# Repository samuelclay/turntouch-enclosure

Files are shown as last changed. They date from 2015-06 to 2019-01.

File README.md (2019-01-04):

# Turn Touch Enclosure - CAD & CAM design files
> All the design files used to make the plastic and wood enclosure in both CAD and CAM

<a href="https://turntouch.com"><br />Available at turntouch.com</a>

[][license-url]



## Screenshots of the Turn Touch enclosure

### Remote stack up


### Wooden case machine fixture


Machining remotes | Machining buttons
:---:|:---:
|  |  | 

## Background

You can read the complete documentation and background on the [Turn Touch blog series](http://ofbrooklyn.com/2019/01/3/building-turntouch/#cad).

## Features

[Turn Touch](https://turntouch.com) is a smart home remote control carved out of beautiful mahogany wood. This is a remote control for Hue lights, Sonos speakers, and all the other connected devices in your home. Turn Touch works on iOS and macOS, giving you control of your music, videos, presentations, and more. 

- [x] **Extraordinary design**: This isn't yet another plastic remote. Turn Touch is carved from solid wood and worked to a show-stopping, textured finish. 
- [x] **Well connected**: Turn Touch connects to most smart devices in your home that speak WiFi. And this is just the first version. Over time, there's no telling what you'll be able to control.
- [x] **Always ready**: Turn Touch is always on, always connected, and always ready to take your breath away. Once you connect your Turn Touch via Bluetooth it stays connected and always available, even without the Turn Touch app actively running. And there's no delay, when you press a button the result is instant.
- [x] **Built to last**: Not only will your Turn Touch stand up to drops and shock — its entire circuit board can be inexpensively replaced with newer, future wireless tech. You won't have to buy a new remote every time Apple comes out with a new phone. And instead of flimsy plastic clasps, a set of 8 strong magnets invisibly hold the remote together. 

## Requirements

- Windows 10
- Autodesk Inventor 2018

## Contribute

We would love you for the contribution to the **Turn Touch enclosure**. Submit a Pull Request with your changes or additions and I'd love to talk about merging it. 

## Turn Touch open source repositories and documentation

Everything about Turn Touch is open source and well documented. Here are all of Turn Touch's repos:

* [Turn Touch Mac OS app](https://github.com/samuelclay/turntouch-mac/)
* [Turn Touch iOS app](https://github.com/samuelclay/turntouch-ios/)
* [Turn Touch remote firmware and board layout](https://github.com/samuelclay/turntouch-remote/)
* [Turn Touch enclosure, CAD, and CAM](https://github.com/samuelclay/turntouch-enclosure/)

The entire Turn Touch build process is also documented:
* <a href="http://ofbrooklyn.com/2019/01/3/building-turntouch/">Everything you need to build your own Turn Touch smart remote<br /></a>
* <a href="http://ofbrooklyn.com/2019/01/3/building-turntouch/#firmware">Step one: Laying out the buttons and writing the firmware <br /></a>
* <a href="http://ofbrooklyn.com/2019/01/3/building-turntouch/#cad">Step two: Designing the remote to have perfect button clicks <br /></a>
* <a href="http://ofbrooklyn.com/2019/01/3/building-turntouch/#cnc">Step three: CNC machining and fixturing to accurately cut wood <br /></a>
* <a href="http://ofbrooklyn.com/2019/01/3/building-turntouch/#laser">Step four: Inlaying the mother of pearl <br /></a>

## Author

Samuel Clay – [@samuelclay](https://twitter.com/samuelclay) – [samuelclay.com](http://samuelclay.com)

Distributed under the MIT license. See ``LICENSE`` for more information.

[https://github.com/samuelclay/turntouch-mac](https://github.com/samuelclay)

[swift-image]:https://img.shields.io/badge/swift-3.0-orange.svg
[swift-url]: https://swift.org/
[license-image]: https://img.shields.io/badge/License-MIT-blue.svg
[license-url]: LICENSE
[travis-image]: https://img.shields.io/travis/dbader/node-datadog-metrics/master.svg?style=flat-square
[travis-url]: https://travis-ci.org/dbader/node-datadog-metrics
[codebeat-image]: https://codebeat.co/badges/c19b47ea-2f9d-45df-8458-b2d952fe9dad
[codebeat-url]: https://codebeat.co/projects/github-com-vsouza-awesomeios-com

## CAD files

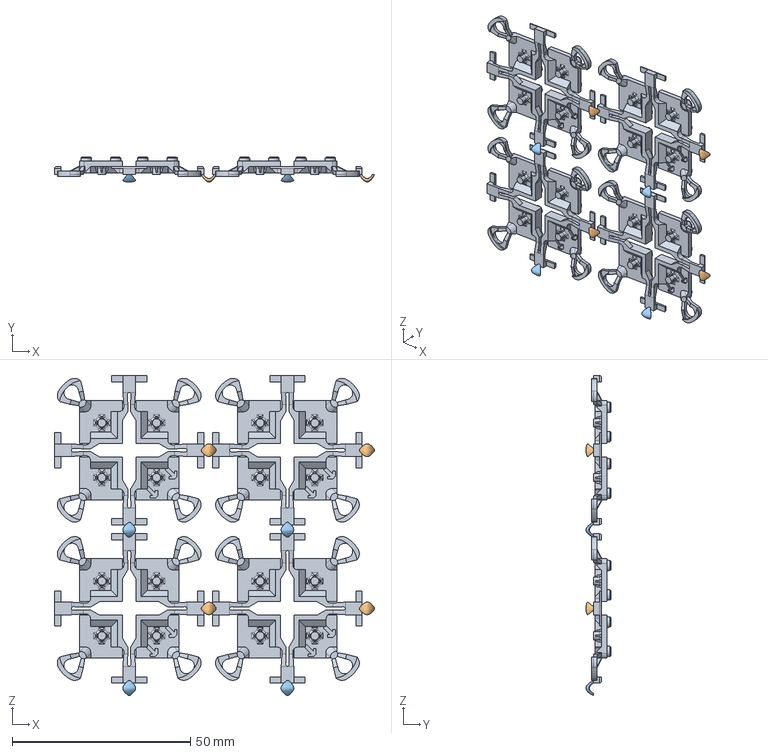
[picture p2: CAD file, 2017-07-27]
inventor/STEPs/Remote Buttons Print Assembly.stp
89.9 x 7.06 x 89.9 mm
Remote Buttons x 4

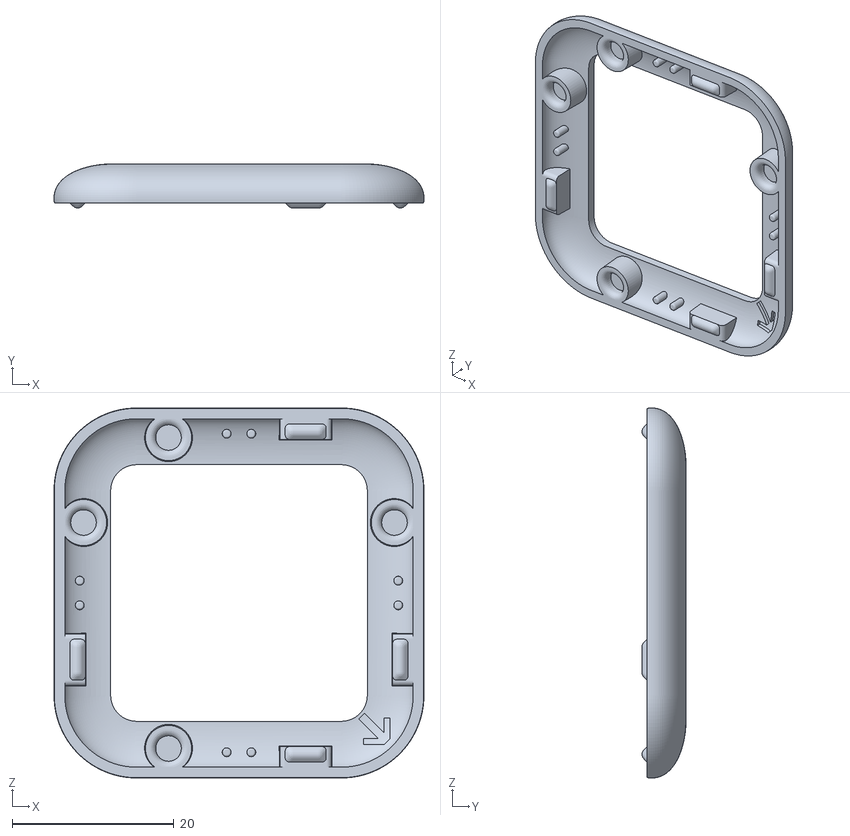
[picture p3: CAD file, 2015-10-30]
revisions/Turn Touch Remote Rev. 29/Remote Assembly_Remote Top_1.stl
45.8 x 5.45 x 45.8

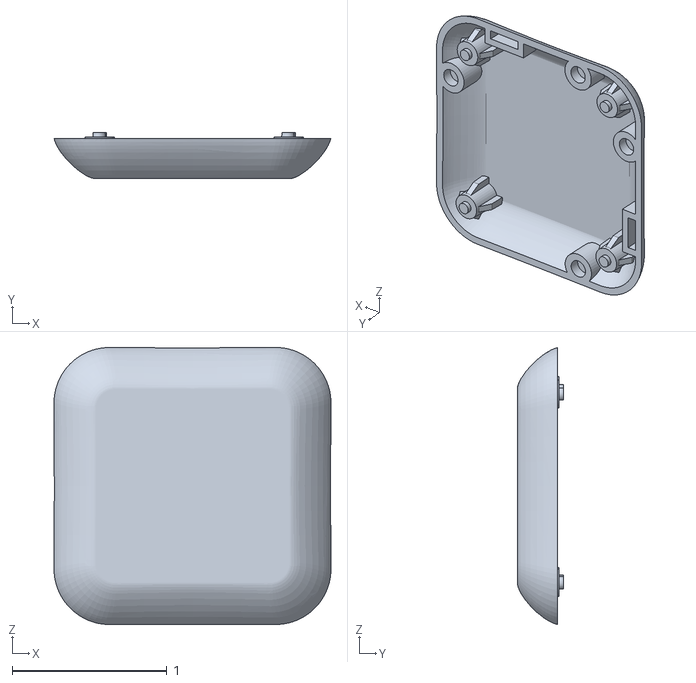
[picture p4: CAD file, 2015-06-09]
solidworks/STLs/Remote Assembly - Remote Bottom-1.STL
1.79 x 0.3 x 1.79

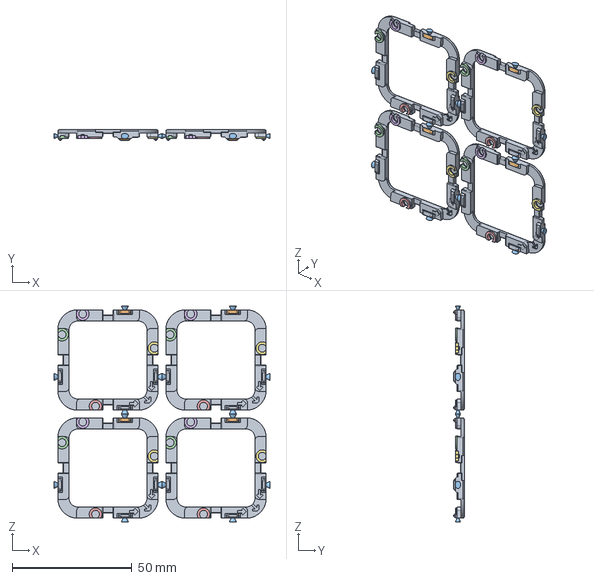
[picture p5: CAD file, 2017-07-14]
inventor/STEPs/Remote Top Print Assembly.stp
90.3 x 4.48 x 90.3 mm
Remote Top x 4

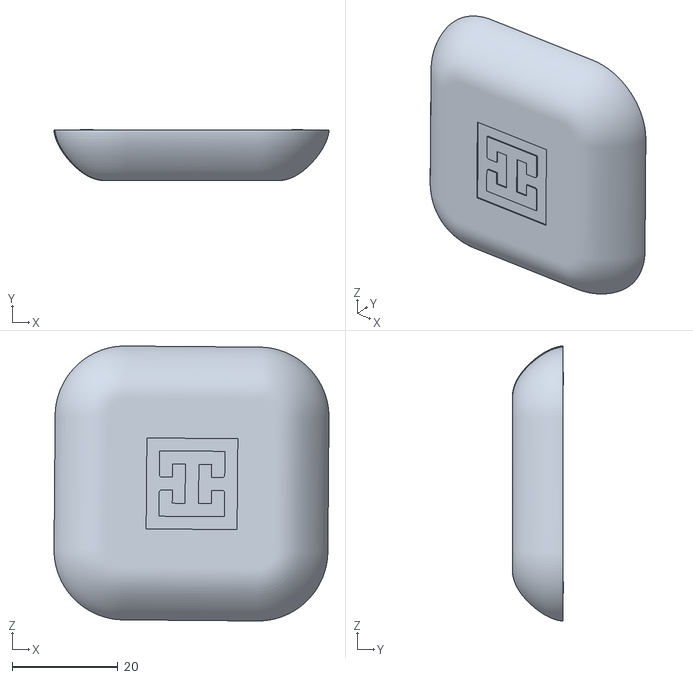
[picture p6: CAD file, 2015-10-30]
revisions/Turn Touch Remote Rev. 29/Remote Assembly_Case Bottom_5.stl
52.1 x 9.75 x 52.1

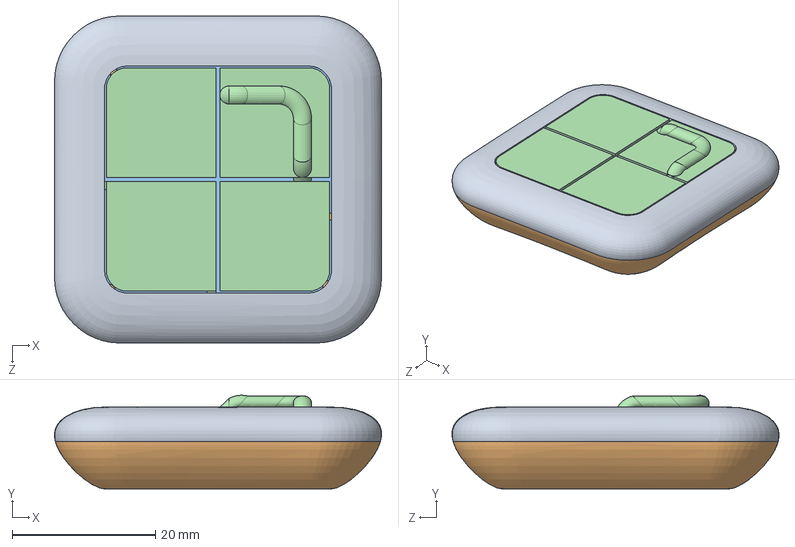
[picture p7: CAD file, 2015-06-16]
solidworks/Remote Assembly.SLDASM
45.7 x 13.1 x 45.7 mm
Remote Top
Remote Buttons

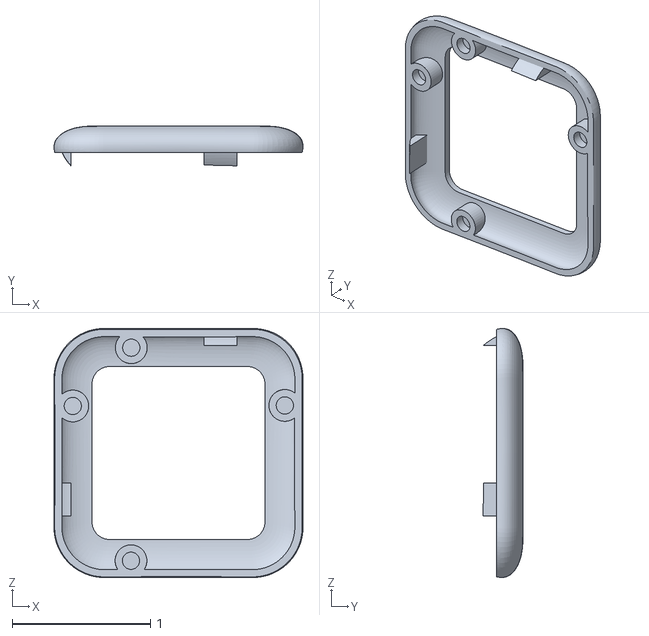
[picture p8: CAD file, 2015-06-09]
solidworks/STLs/Remote Assembly - Remote Top-1.STL
1.80 x 0.29 x 1.80

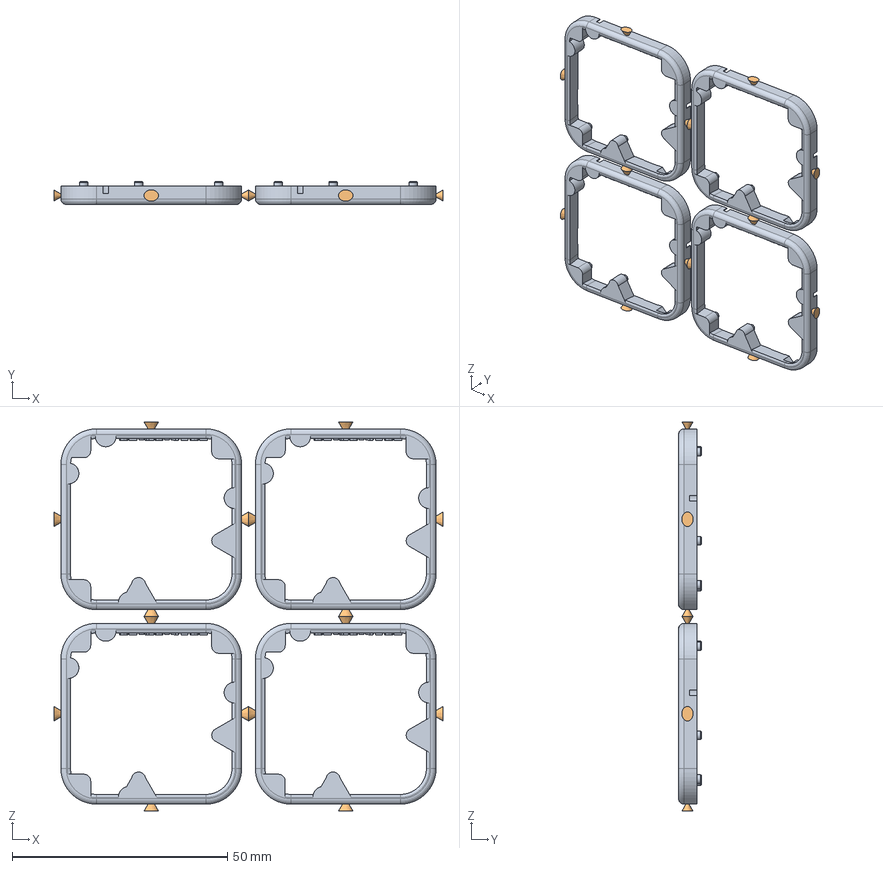
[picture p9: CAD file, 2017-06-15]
inventor/STEPs/Remote Bottom Print Assembly.stp
90.3 x 5.33 x 90.3 mm
Remote Bottom x 4

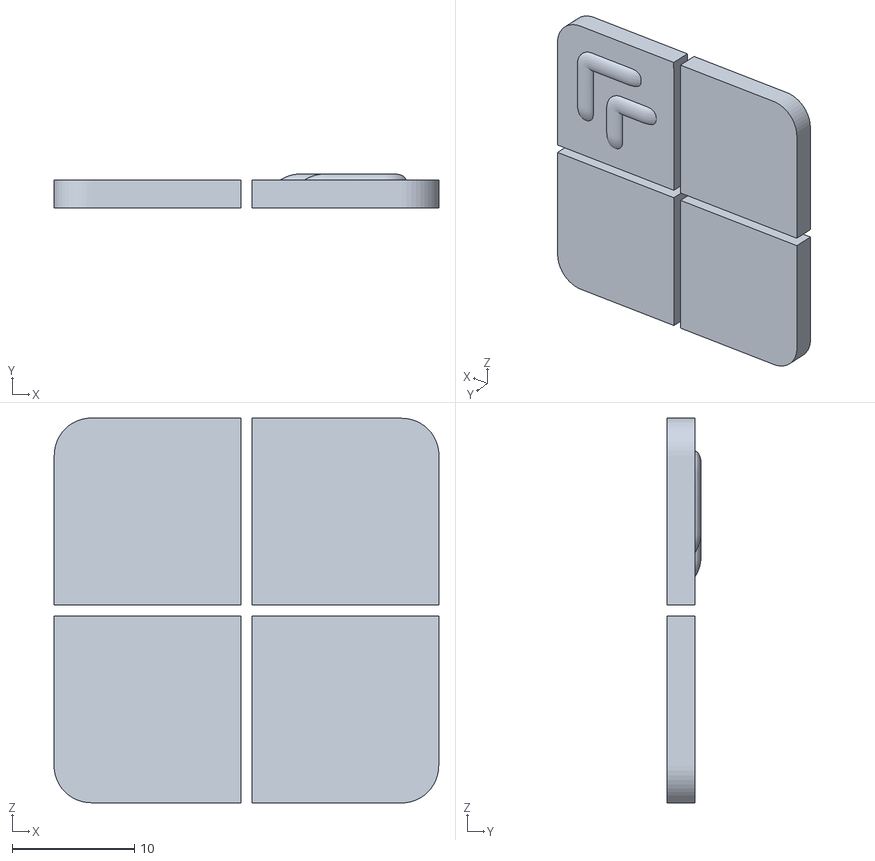
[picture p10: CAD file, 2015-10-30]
revisions/Turn Touch Remote Rev. 29/Remote Assembly_Case Buttons_6.stl
31.5 x 2.79 x 31.5

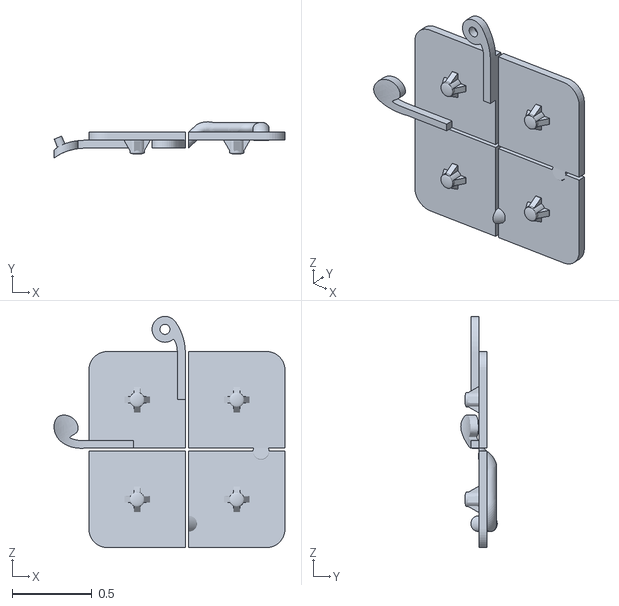
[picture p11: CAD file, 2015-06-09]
solidworks/STLs/Remote Assembly - Remote Buttons-1.STL
1.45 x 0.229 x 1.45

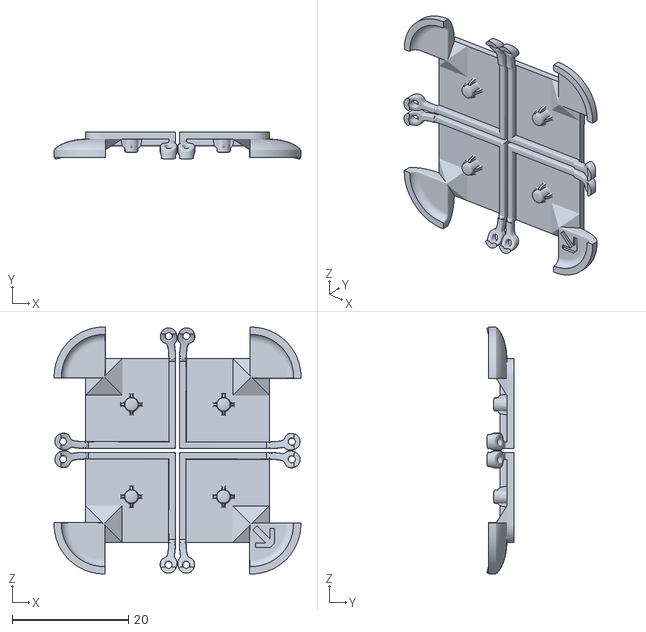
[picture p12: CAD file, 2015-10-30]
revisions/Turn Touch Remote Rev. 29/Remote Assembly_Remote Buttons_2.stl
42.6 x 4.73 x 42.6

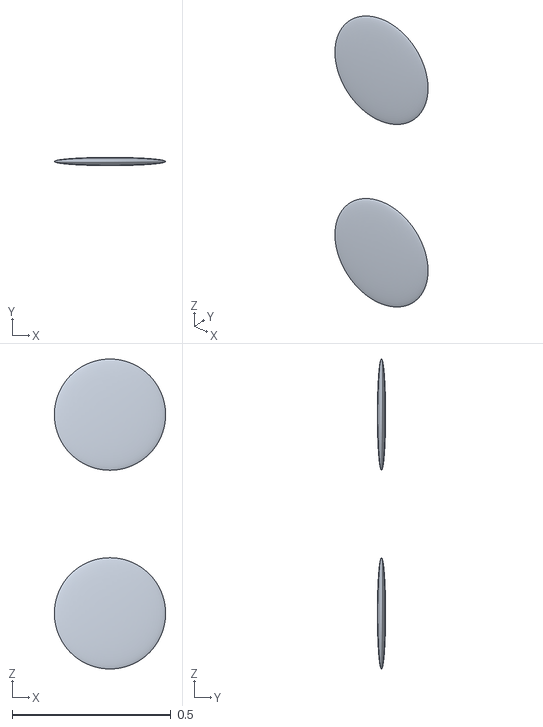
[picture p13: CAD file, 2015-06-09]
solidworks/STLs/Remote Assembly - PCB-3.STL
0.35 x 0.026 x 0.975

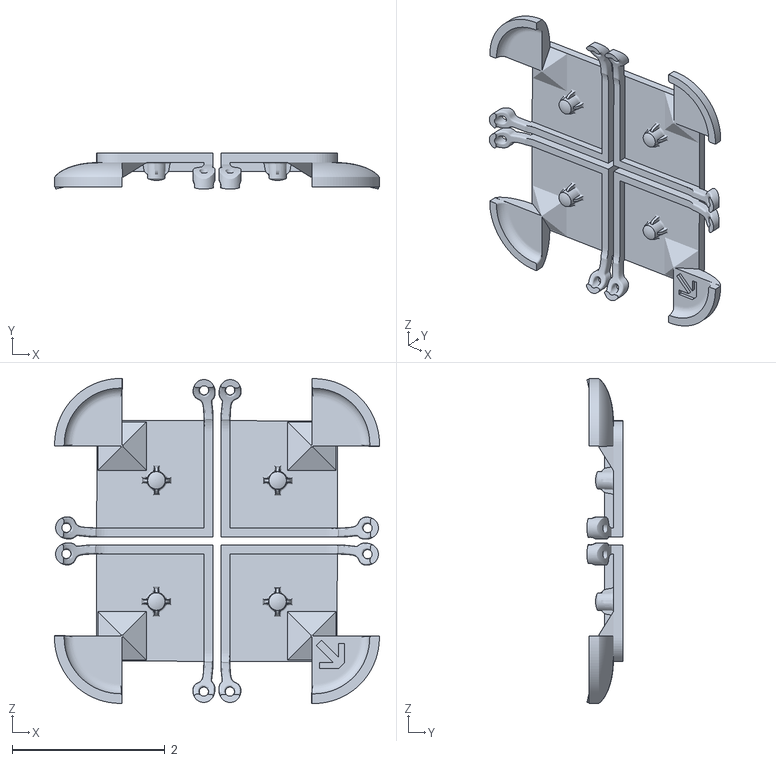
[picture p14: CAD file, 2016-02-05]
inventor/STLs/Remote Assembly_Remote Buttons_2.stl
4.26 x 0.473 x 4.26

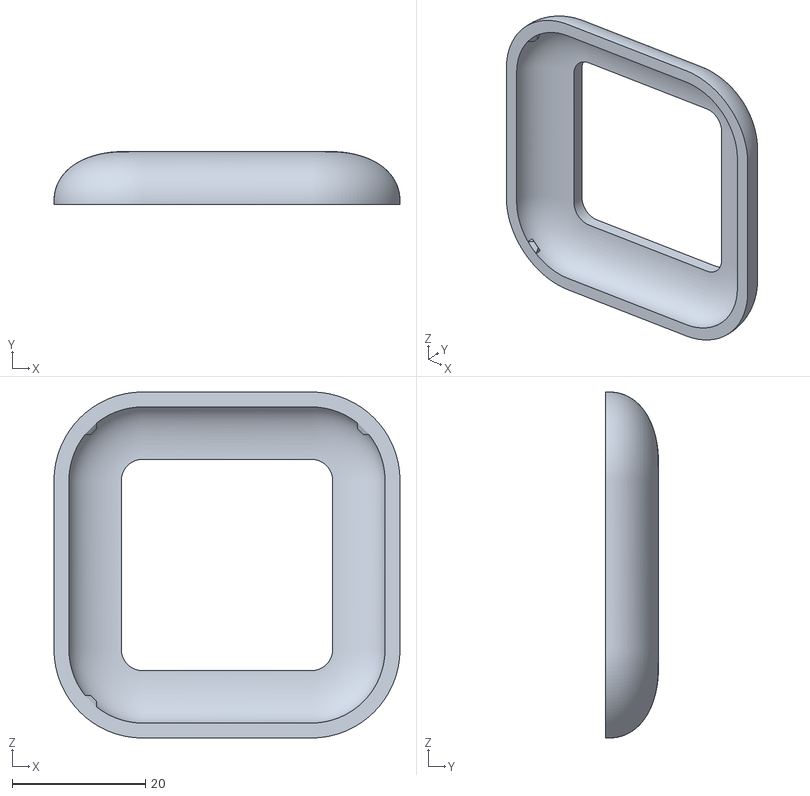
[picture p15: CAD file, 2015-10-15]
revisions/Turn Touch Remote Rev. 29/Remote Assembly_Case Top_4.stl
52.0 x 7.92 x 52.0

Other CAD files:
inventor/STLs/Remote Assembly_Remote Top_1.stl
revisions/Turn Touch Remote Rev. 29/Remote Assembly_Eagle PCB rev 21_7.stl
inventor/STLs/Remote Assembly_Remote Bottom_3.stl
revisions/Turn Touch Remote Rev. 29/Remote Assembly_Remote Bottom_3.stl
Remote Enclosure v2.3dm
Remote Enclosure.skp
Remote enclosure.obj
Remote r14.3dm
archive/rhino/archive/Remote Enclosure v2.3dm
archive/rhino/archive/Remote enclosure.obj
archive/rhino/bottom.stl
archive/rhino/bottom.stp
archive/rhino/bottoms.stp
archive/rhino/button.stl
archive/rhino/button.stp
archive/rhino/buttons.stp
archive/rhino/remote.stp
archive/rhino/top.stl
archive/rhino/top.stp
archive/rhino/tops.stp
archive/sketchup/Remote Enclosure.skp
archive/solidworks/PCB.SLDPRT
archive/solidworks/Remote Assembly.SLDASM
archive/solidworks/Remote Bottom.sldprt
archive/solidworks/Remote Buttons.SLDPRT
archive/solidworks/Remote Shell.SLDPRT
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

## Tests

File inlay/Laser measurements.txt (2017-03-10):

0) Split the case into the top and bottom

   Case width: 2.04"
   Case height: 0.35"

1) Run 'Case Outline' on spoil board

   Select: Center
   Z: 0.75"
   X: (23.5-2.04/2) = 22.48"
   Y: (0.5+2.04/2) = 1.52"

2) Run 'Engraver' on remote case with north ridge, facing down, pointing top left (horizontal mirror)

   Select: Center
   Z: (0.75+0.35) = 1.1"
   X: (23.5-2.04/2) = 22.48"
   Y: (0.5+2.04/2) = 1.52"

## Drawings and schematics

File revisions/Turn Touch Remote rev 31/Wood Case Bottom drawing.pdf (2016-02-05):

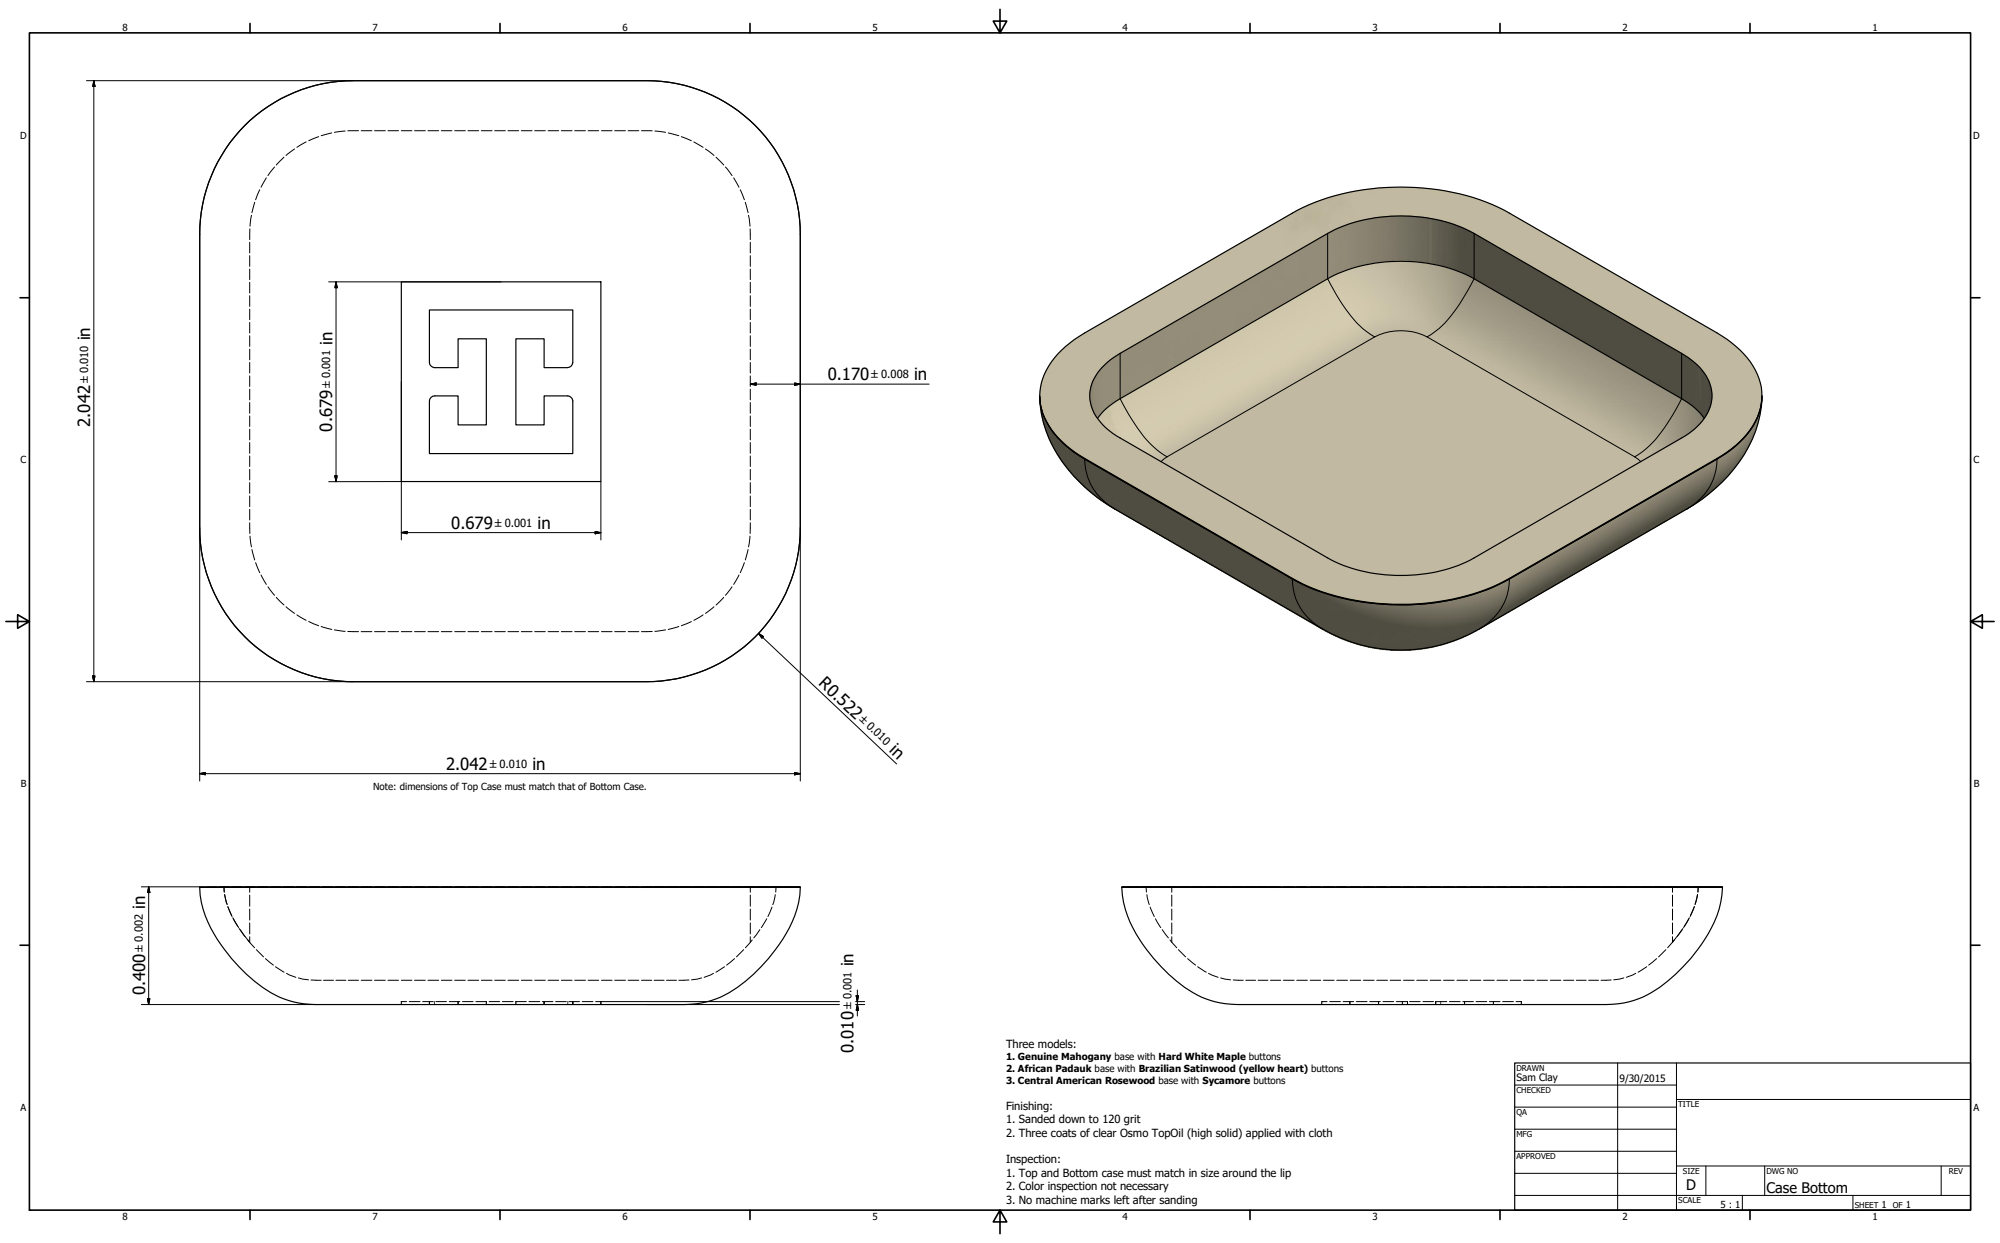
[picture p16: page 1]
SHEET 1 OF 1; DRAWN; CHECKED; MFG; APPROVED; Sam Clay; DWG NO Case Bottom; TITLE; SIZE D; SCALE; REV

Note: dimensions of Top Case must match that of Bottom Case.

Three models:
1. Genuine Mahogany base with Hard White Maple buttons
2. African Padauk base with Brazilian Satinwood (yellow heart) buttons
3. Central American Rosewood base with Sycamore buttons

Finishing:
1. Sanded down to 120 grit
2. Three coats of clear Osmo TopOil (high solid) applied with cloth

Inspection:
1. Top and Bottom case must match in size around the lip
2. Color inspection not necessary
3. No machine marks left after sanding

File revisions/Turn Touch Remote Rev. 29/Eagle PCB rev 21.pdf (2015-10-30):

1.450 in

0.080 in

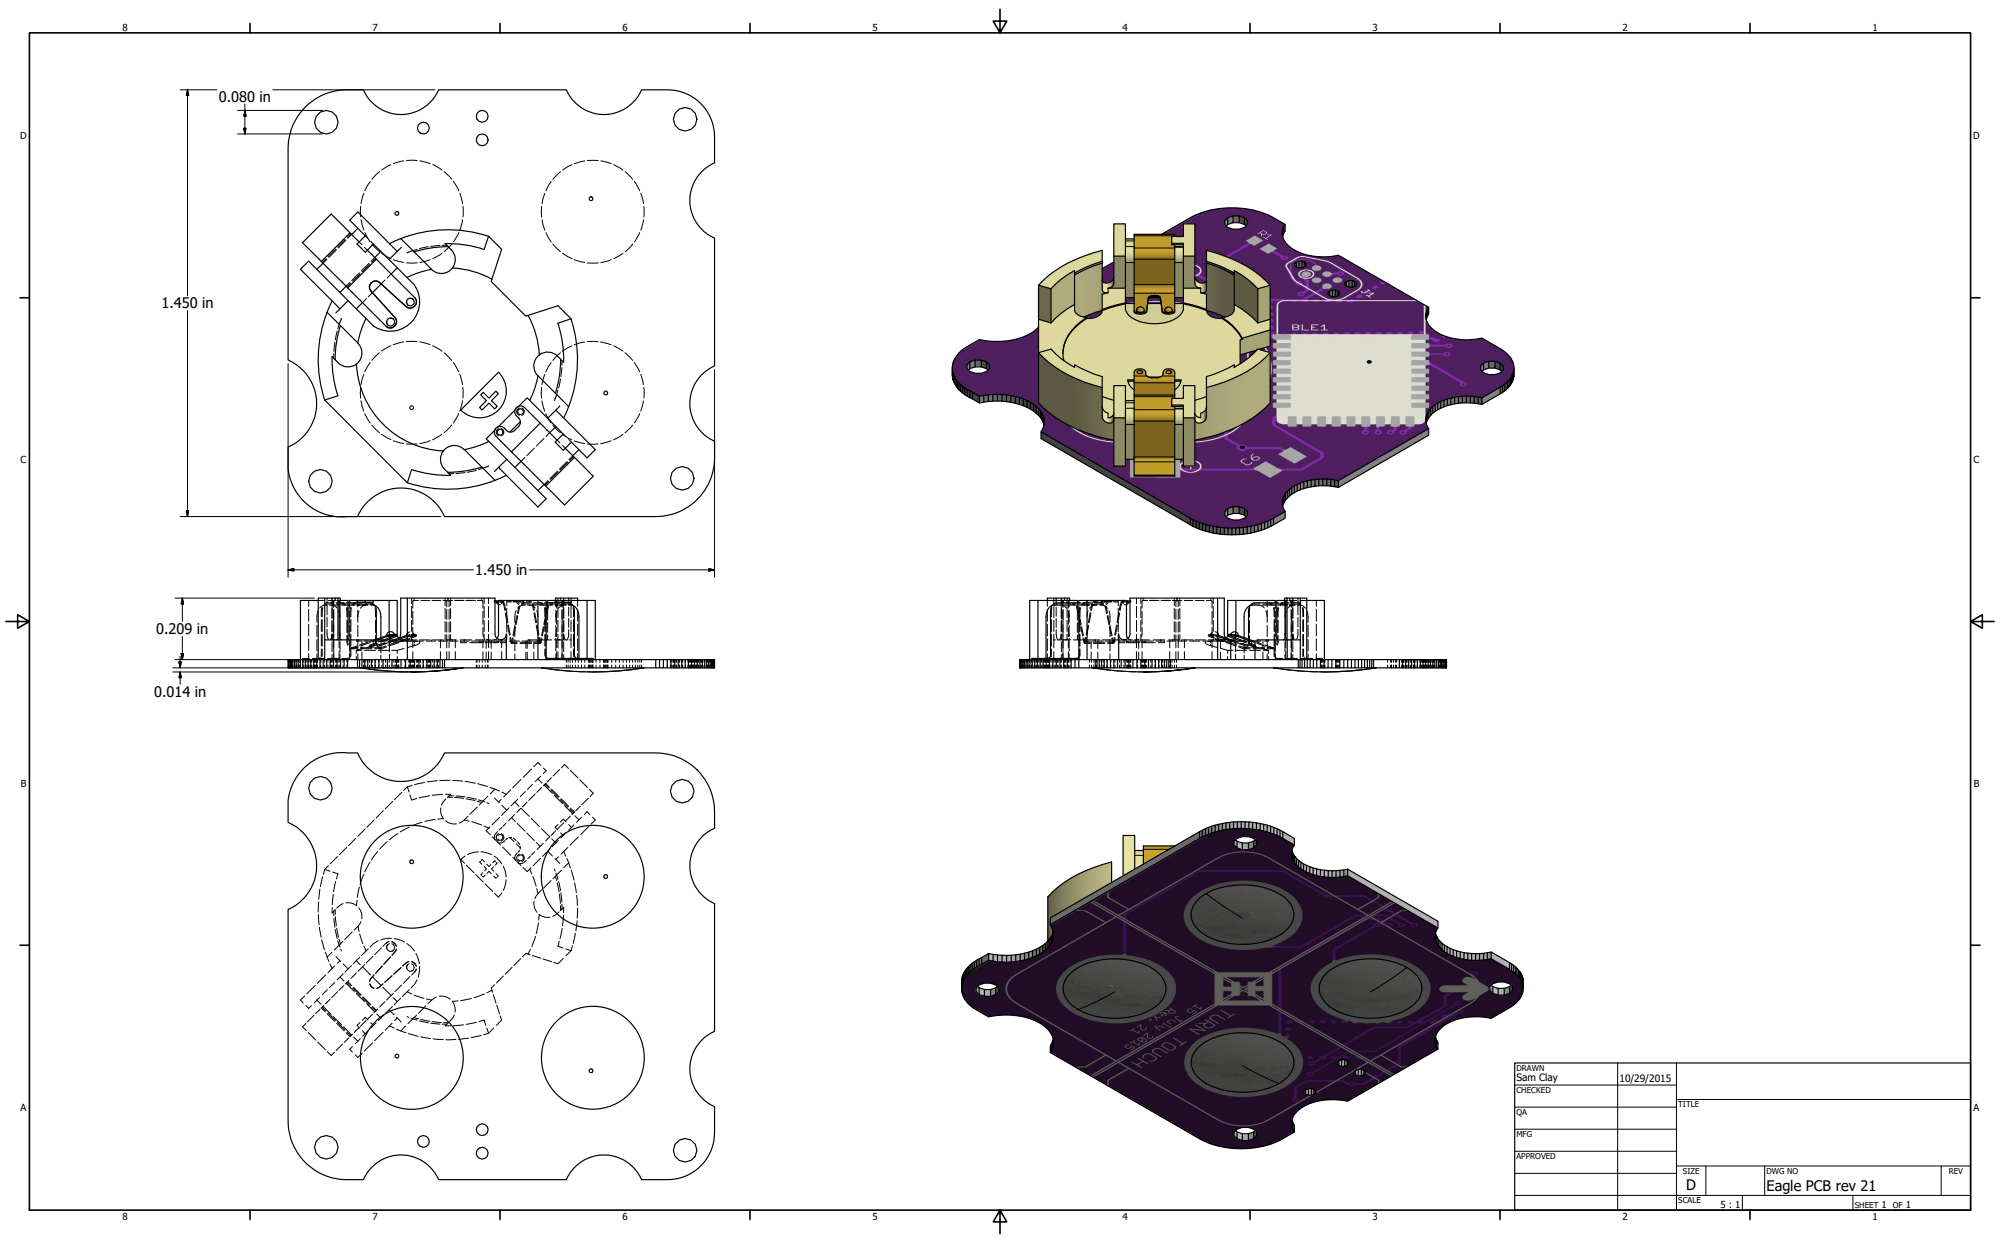
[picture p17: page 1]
SHEET 1 OF 1; DRAWN; CHECKED; MFG; APPROVED; Sam Clay; TITLE; SIZE D; SCALE; REV

DWG NO
Eagle PCB rev 21

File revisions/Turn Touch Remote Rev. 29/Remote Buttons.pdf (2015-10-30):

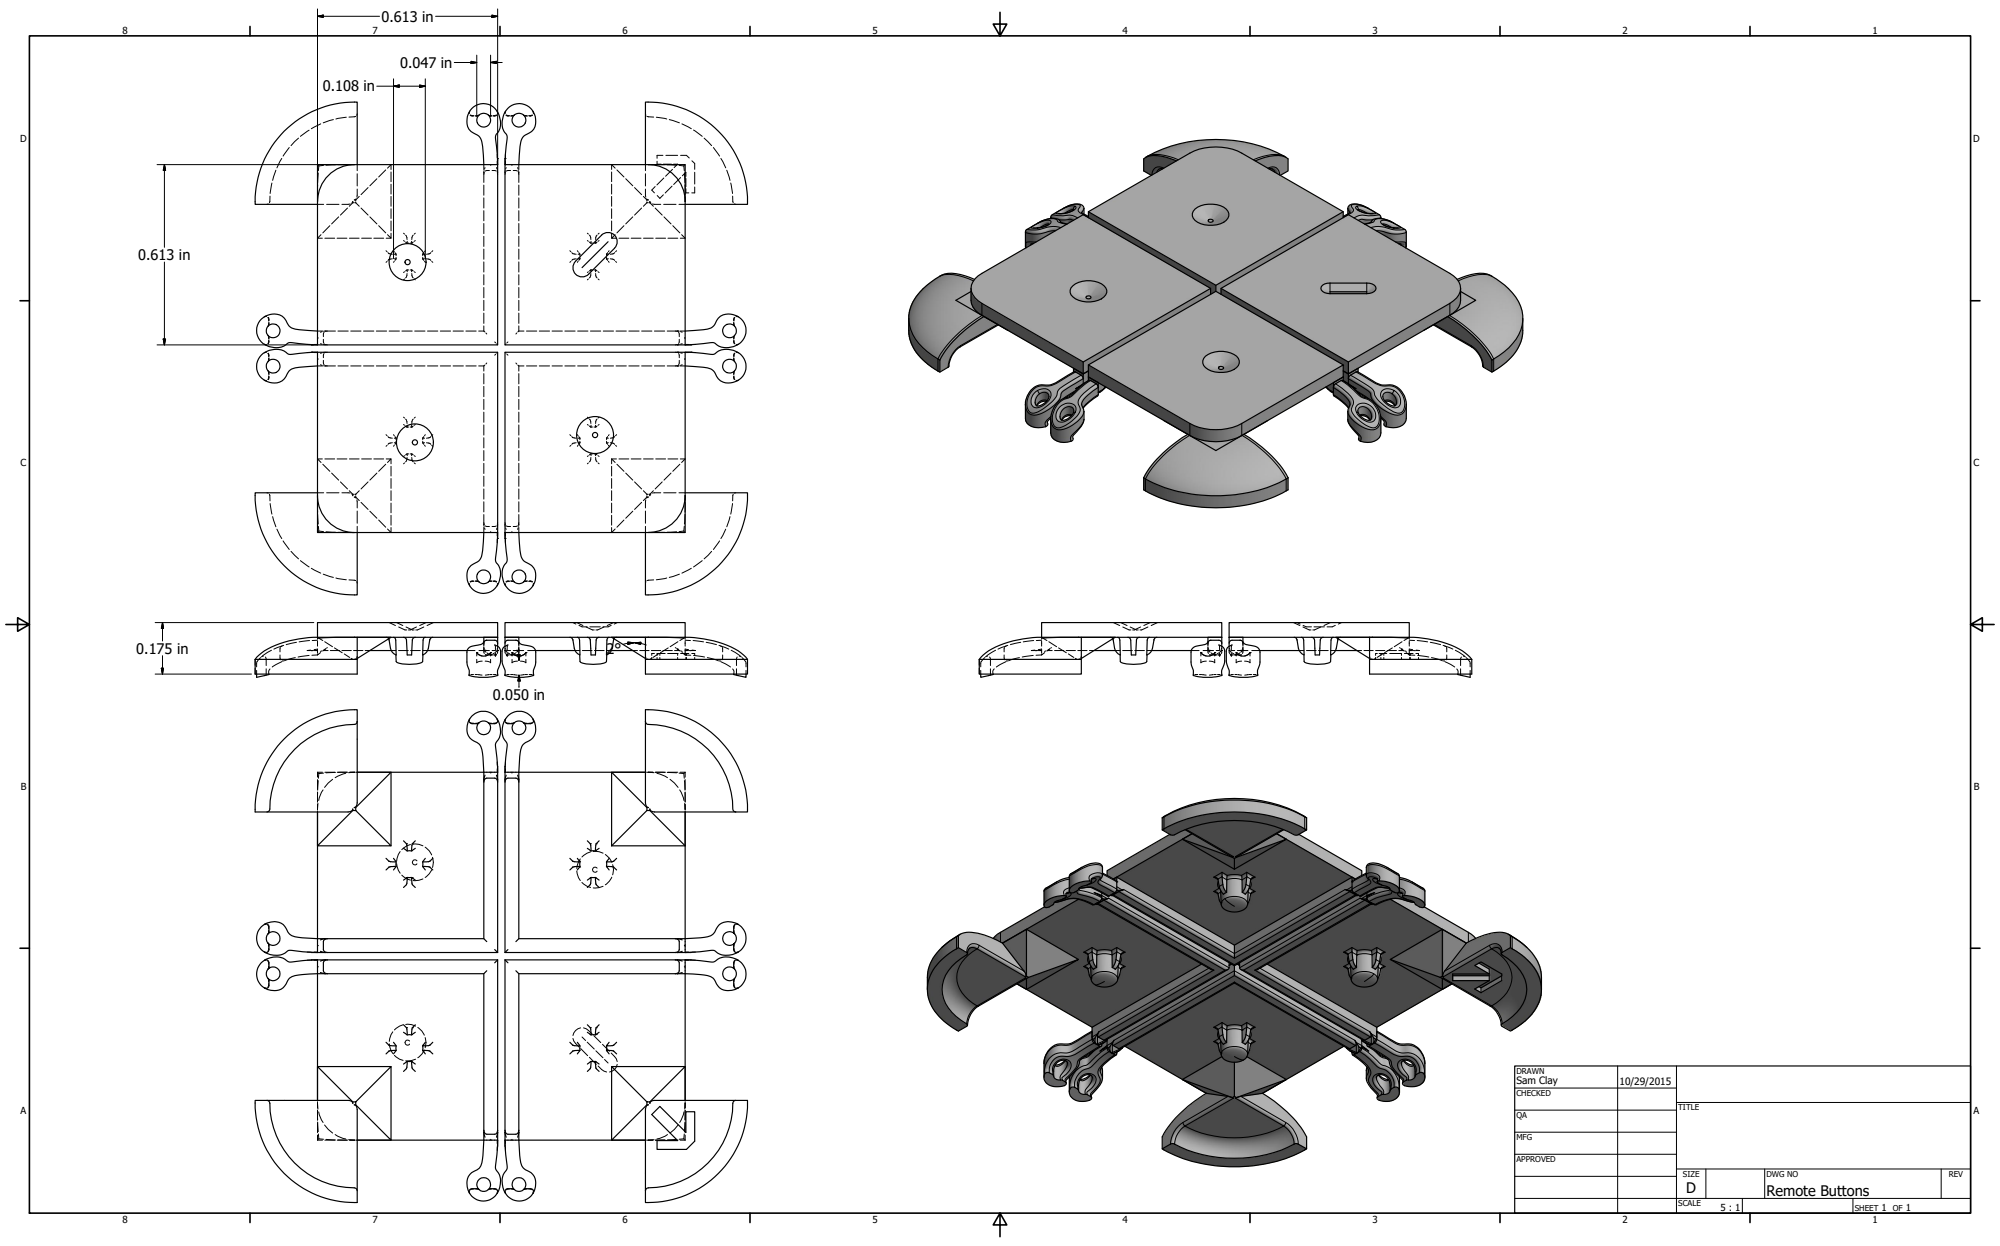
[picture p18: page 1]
SHEET 1 OF 1; DRAWN; CHECKED; MFG; APPROVED; Sam Clay; DWG NO Remote Buttons; TITLE; SIZE D; SCALE; REV

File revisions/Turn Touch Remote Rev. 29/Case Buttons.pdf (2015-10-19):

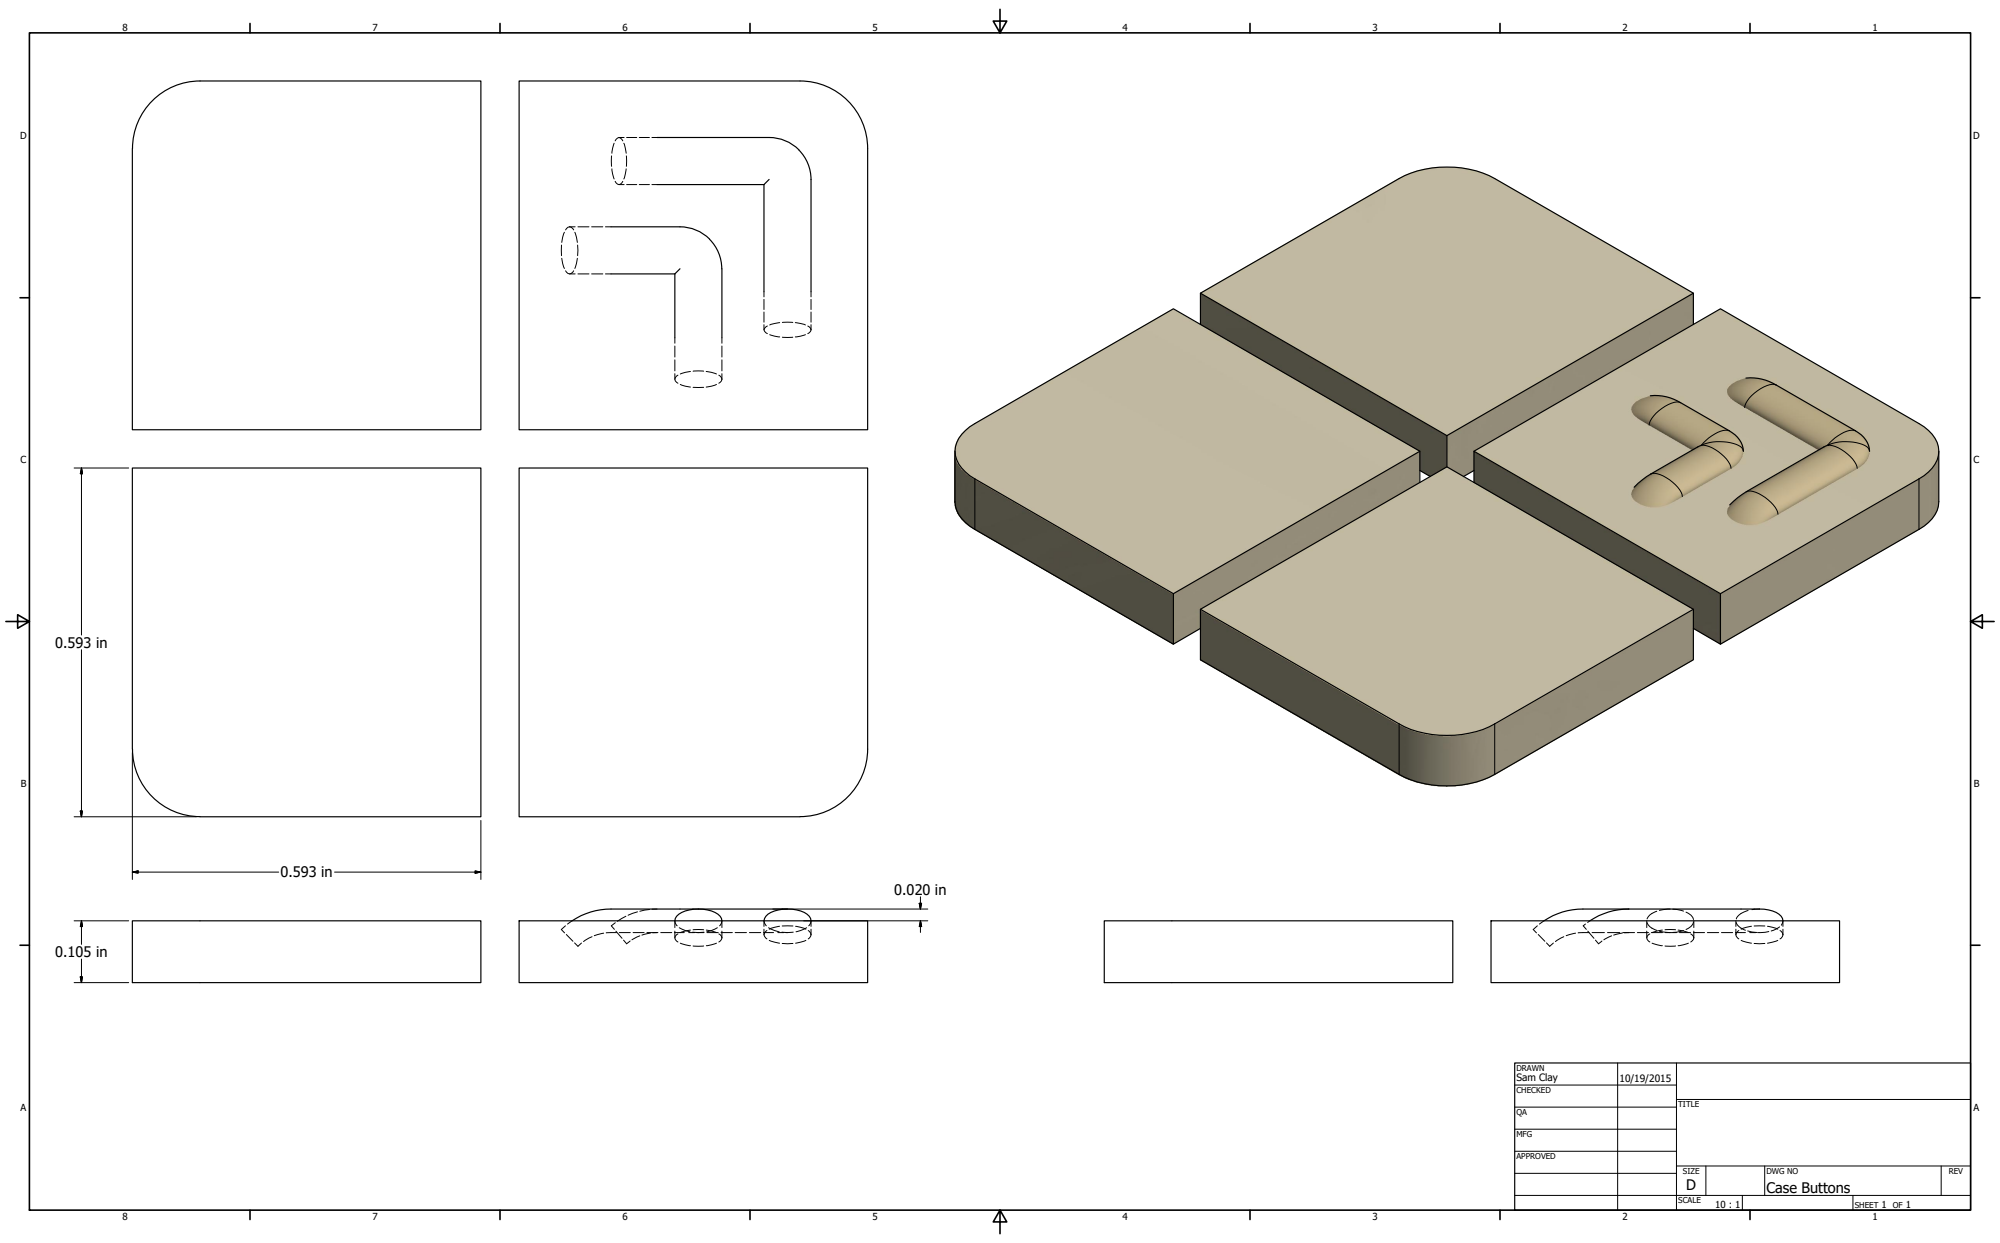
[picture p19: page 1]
SHEET 1 OF 1; DRAWN; CHECKED; MFG; APPROVED; Sam Clay; DWG NO Case Buttons; TITLE; SIZE D; SCALE; REV

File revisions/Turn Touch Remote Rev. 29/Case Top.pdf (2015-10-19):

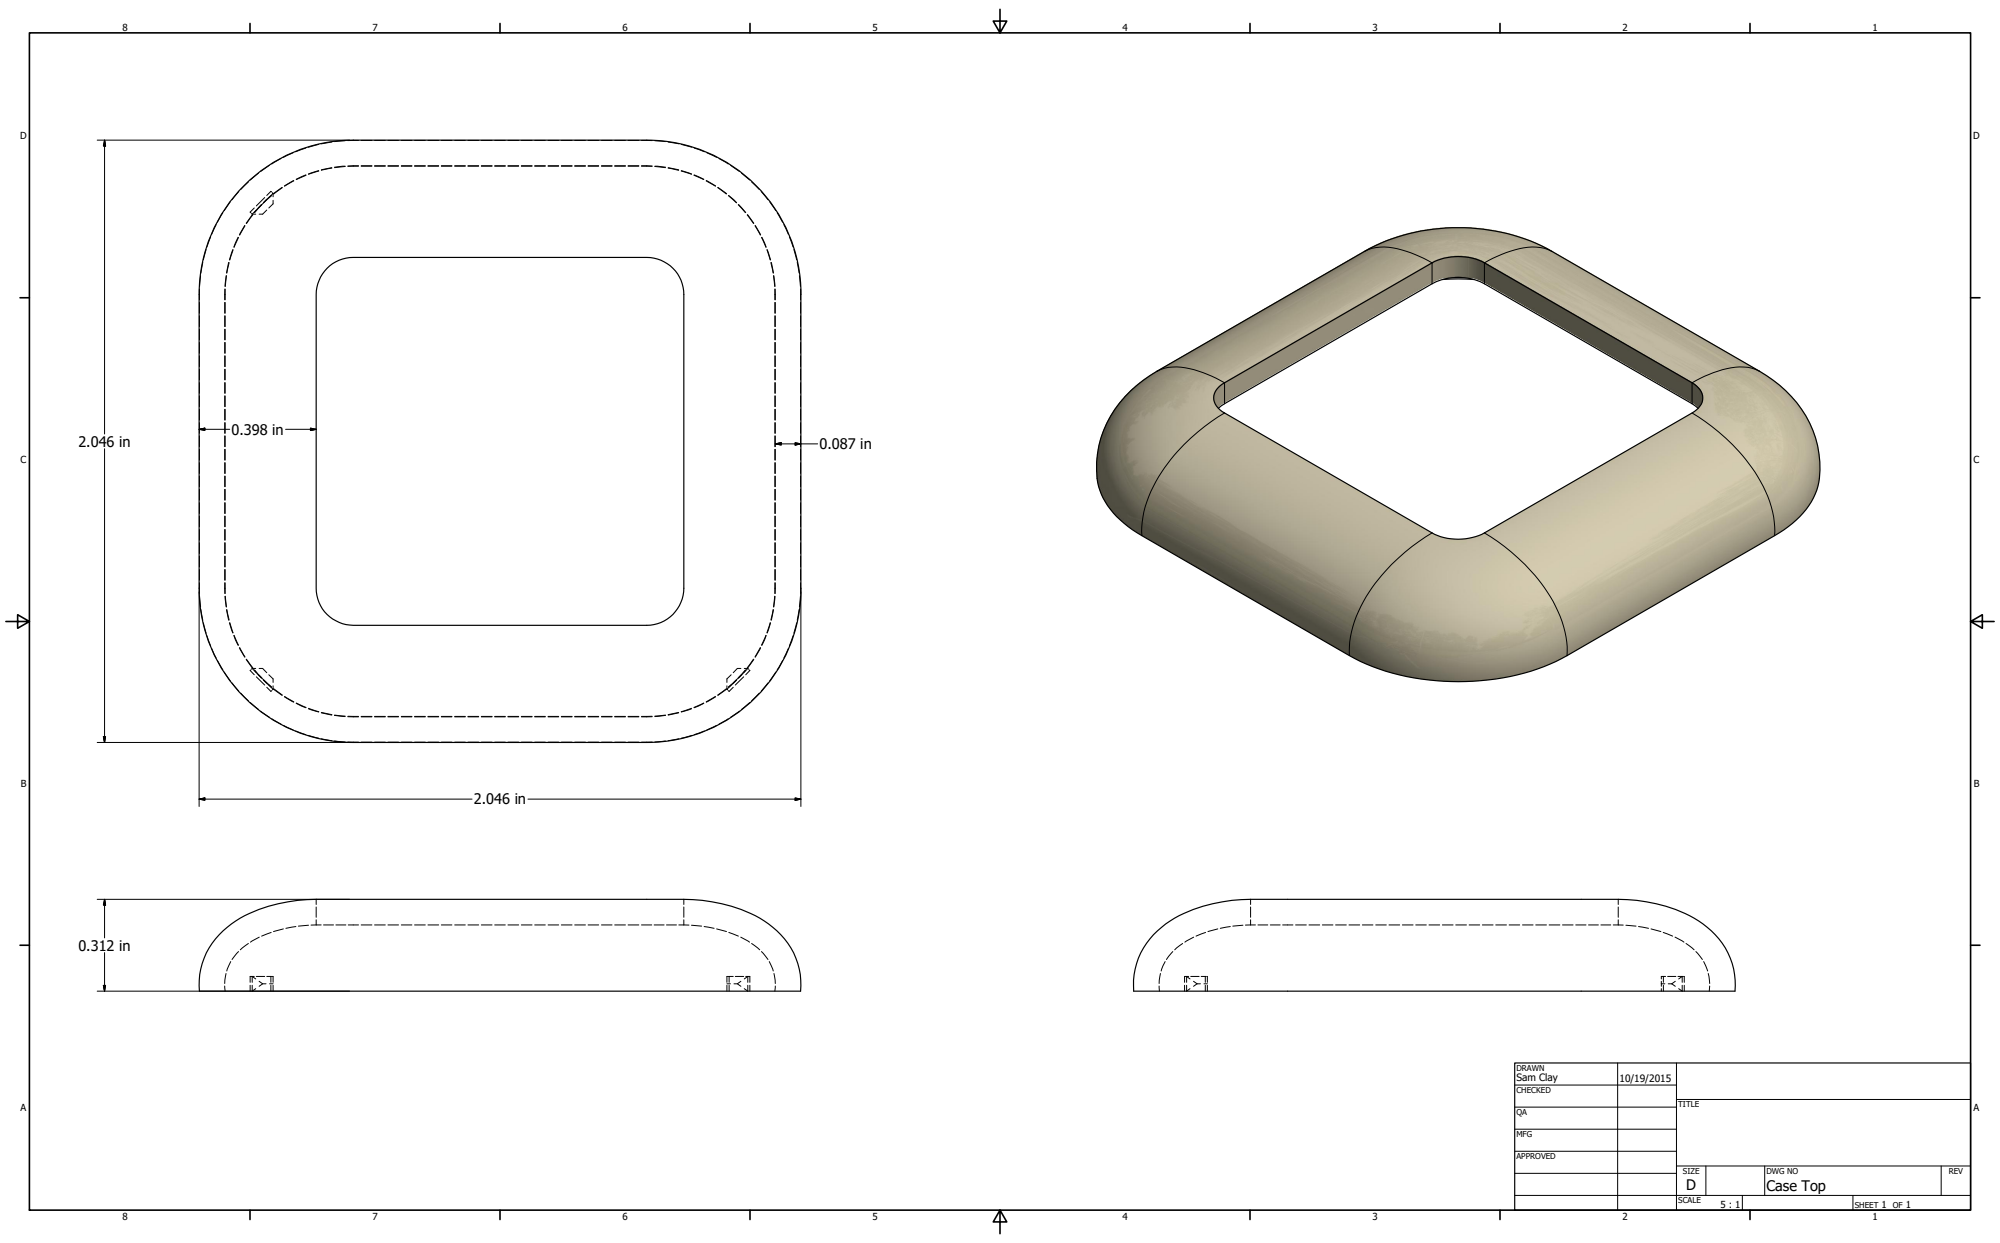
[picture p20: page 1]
SHEET 1 OF 1; DRAWN; CHECKED; MFG; APPROVED; Sam Clay; DWG NO Case Top; TITLE; SIZE D; SCALE; REV

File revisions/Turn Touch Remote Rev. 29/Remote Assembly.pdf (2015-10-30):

1.802 in

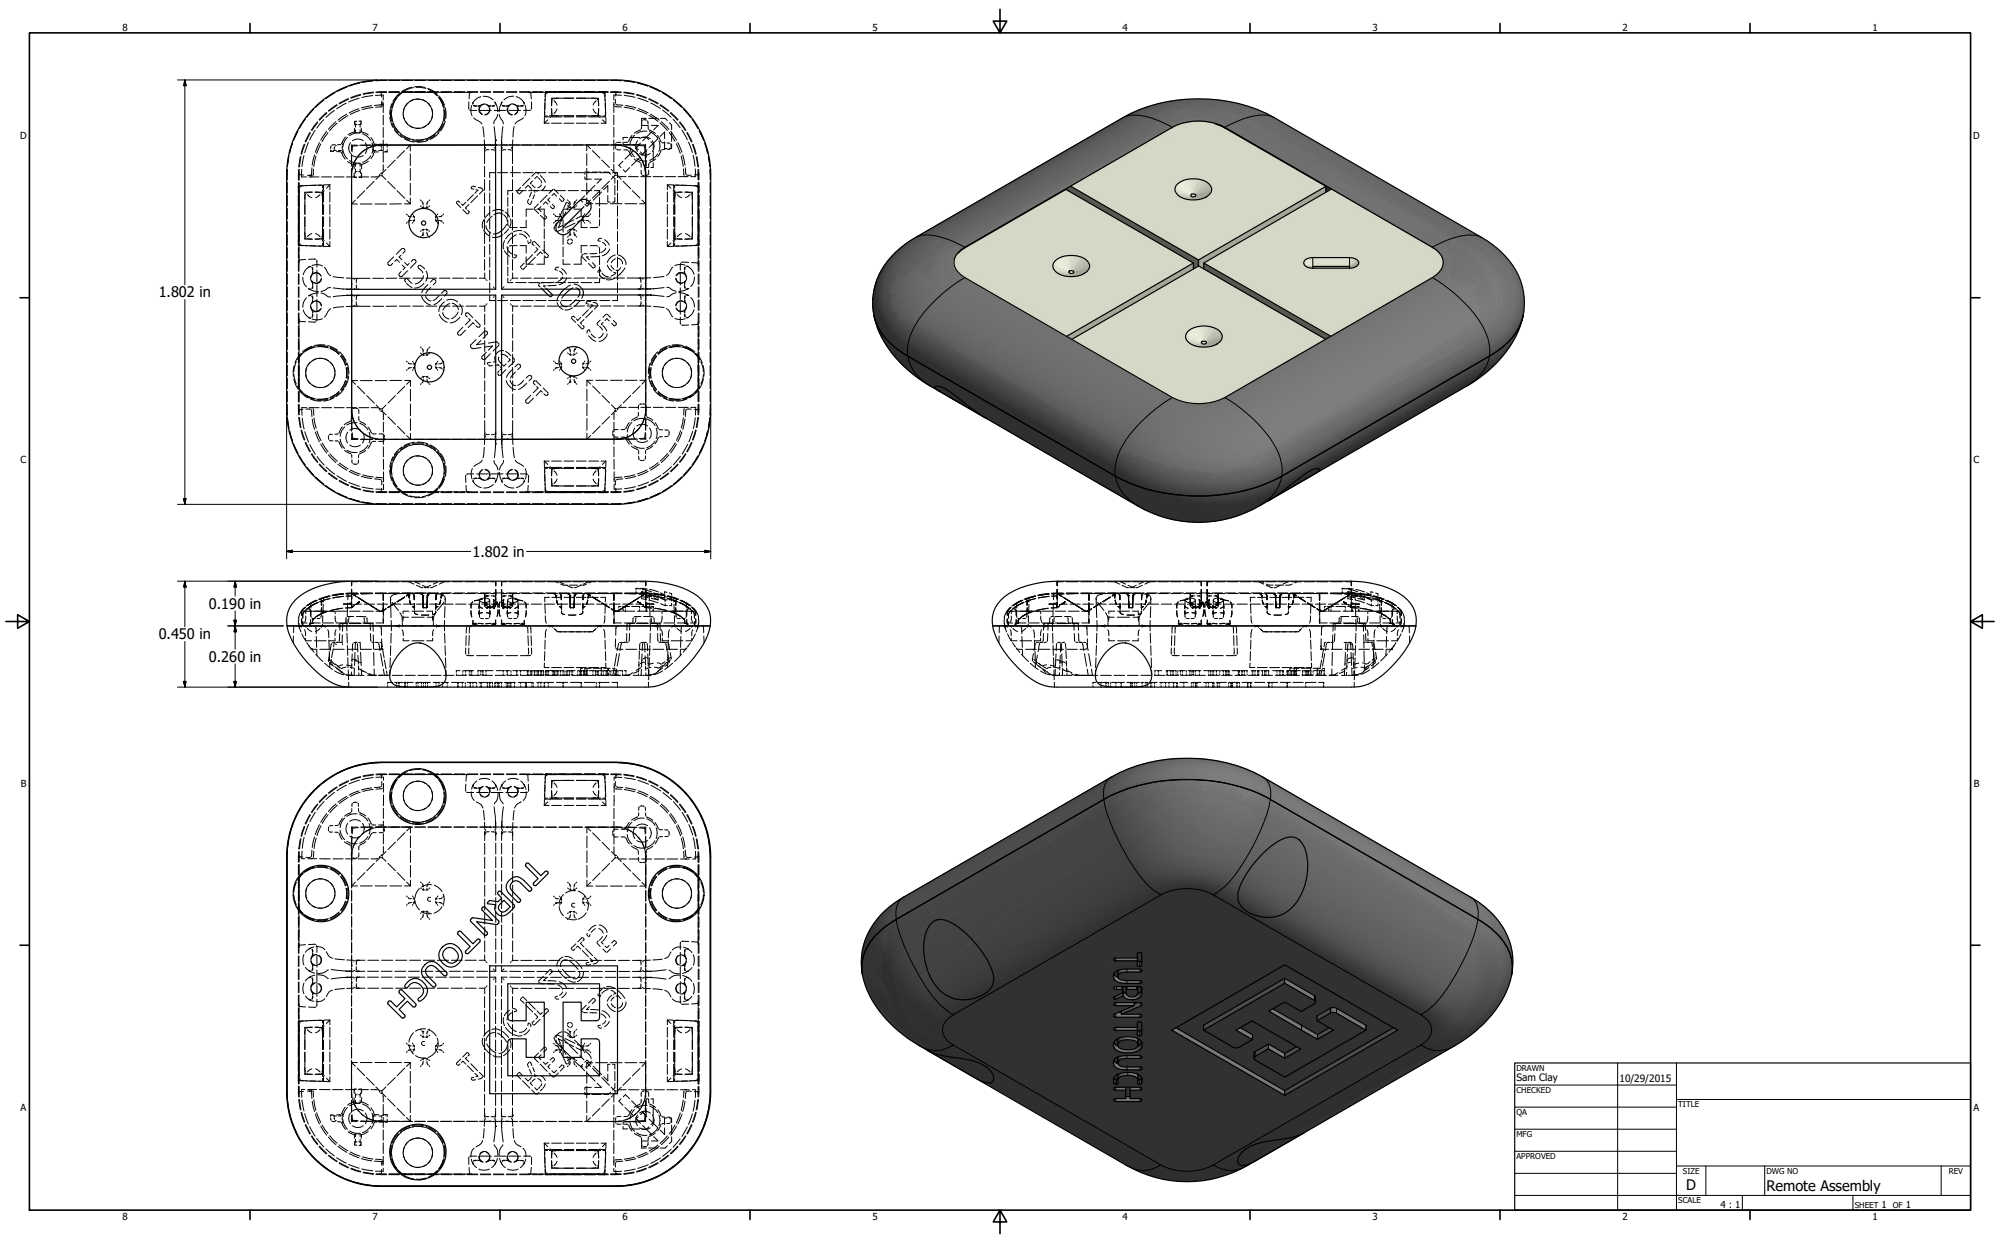
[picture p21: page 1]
SHEET 1 OF 1; DRAWN; CHECKED; MFG; APPROVED; Sam Clay; DWG NO Remote Assembly; TITLE; SIZE D; SCALE; REV

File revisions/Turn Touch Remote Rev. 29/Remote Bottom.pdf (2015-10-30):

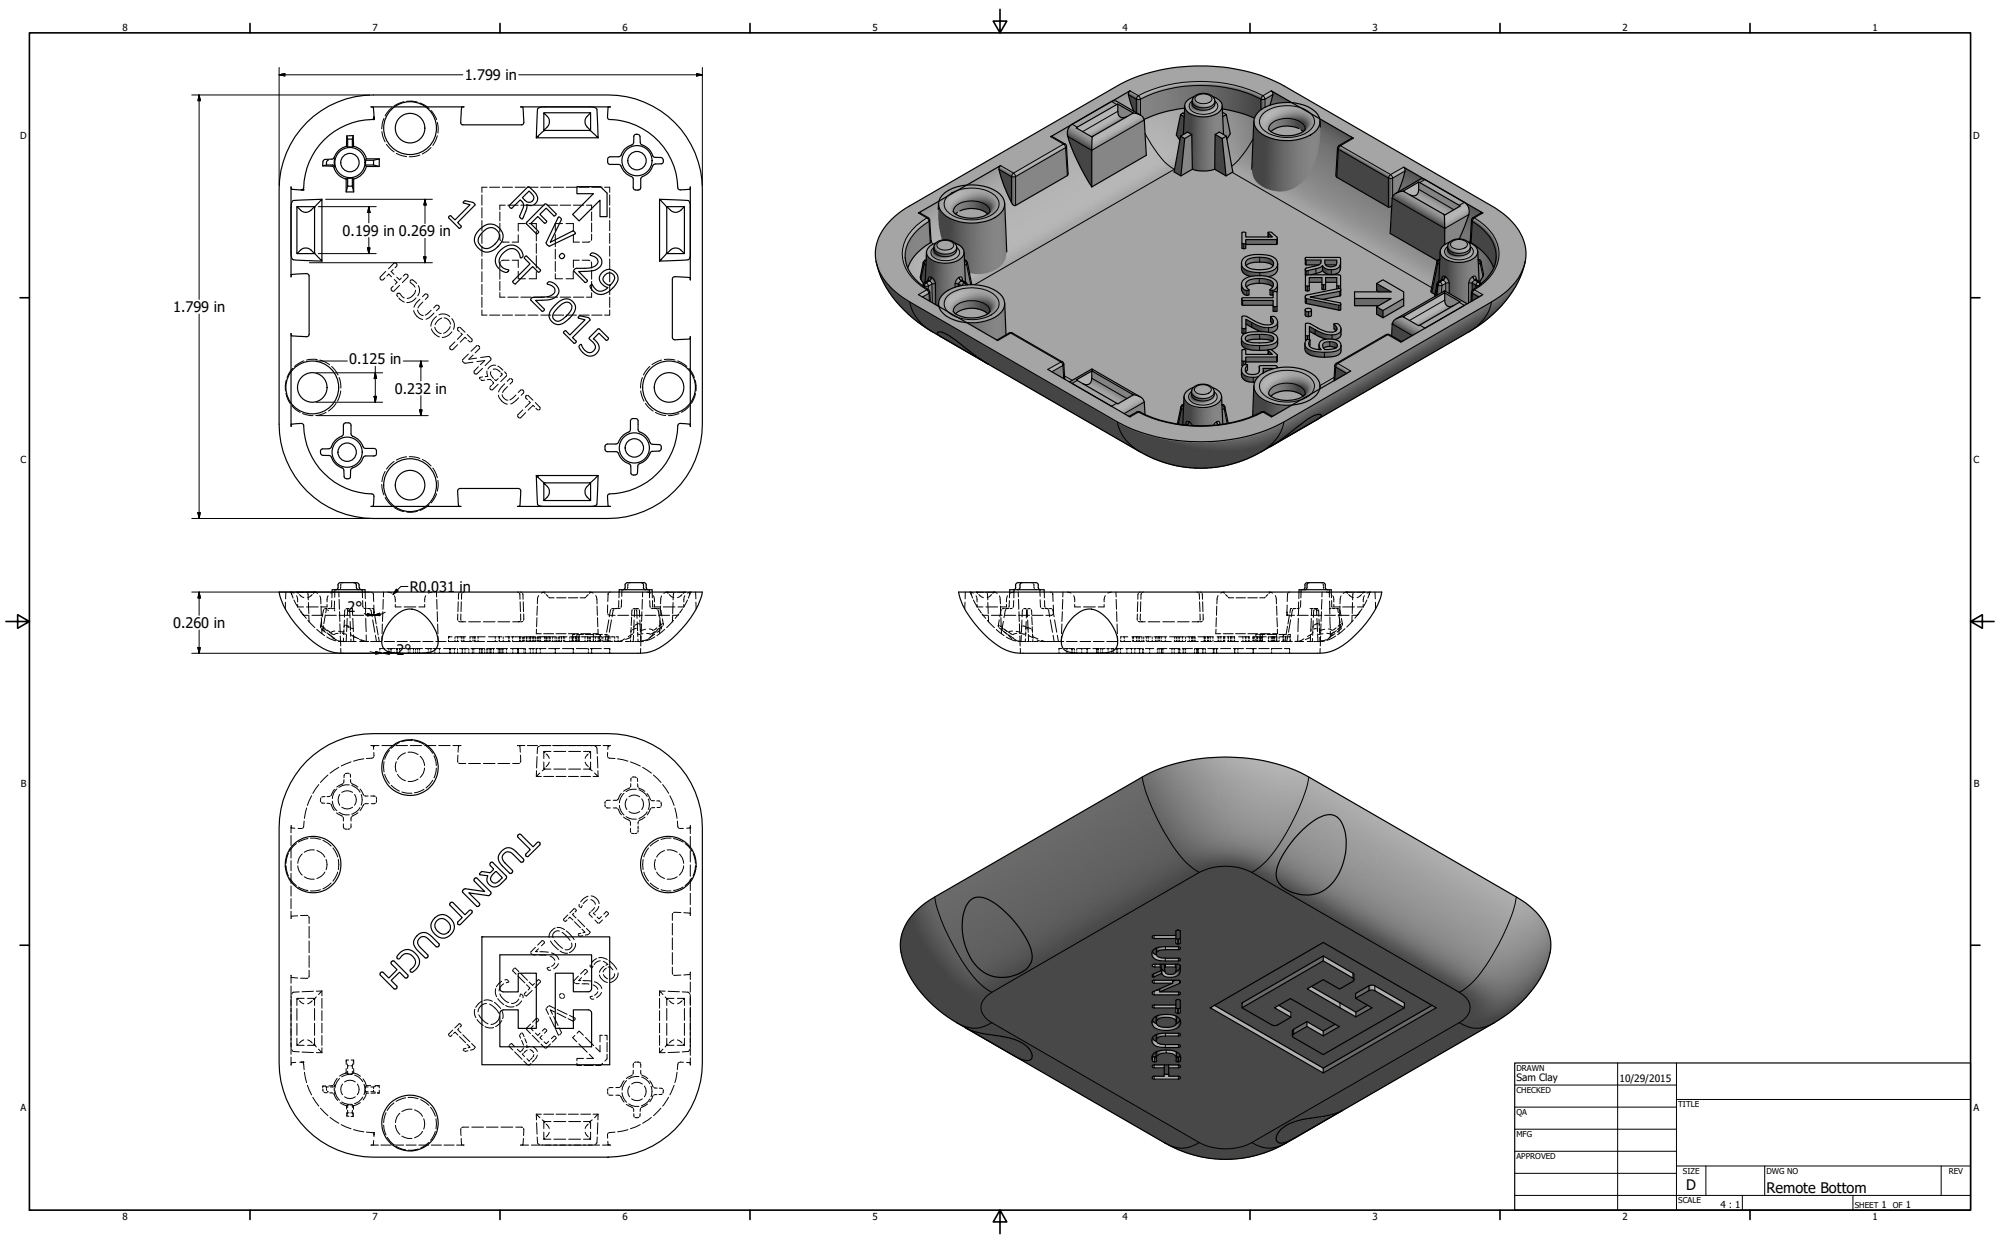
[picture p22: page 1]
SHEET 1 OF 1; DRAWN; CHECKED; MFG; APPROVED; Sam Clay; DWG NO Remote Bottom; TITLE; SIZE D; SCALE; REV

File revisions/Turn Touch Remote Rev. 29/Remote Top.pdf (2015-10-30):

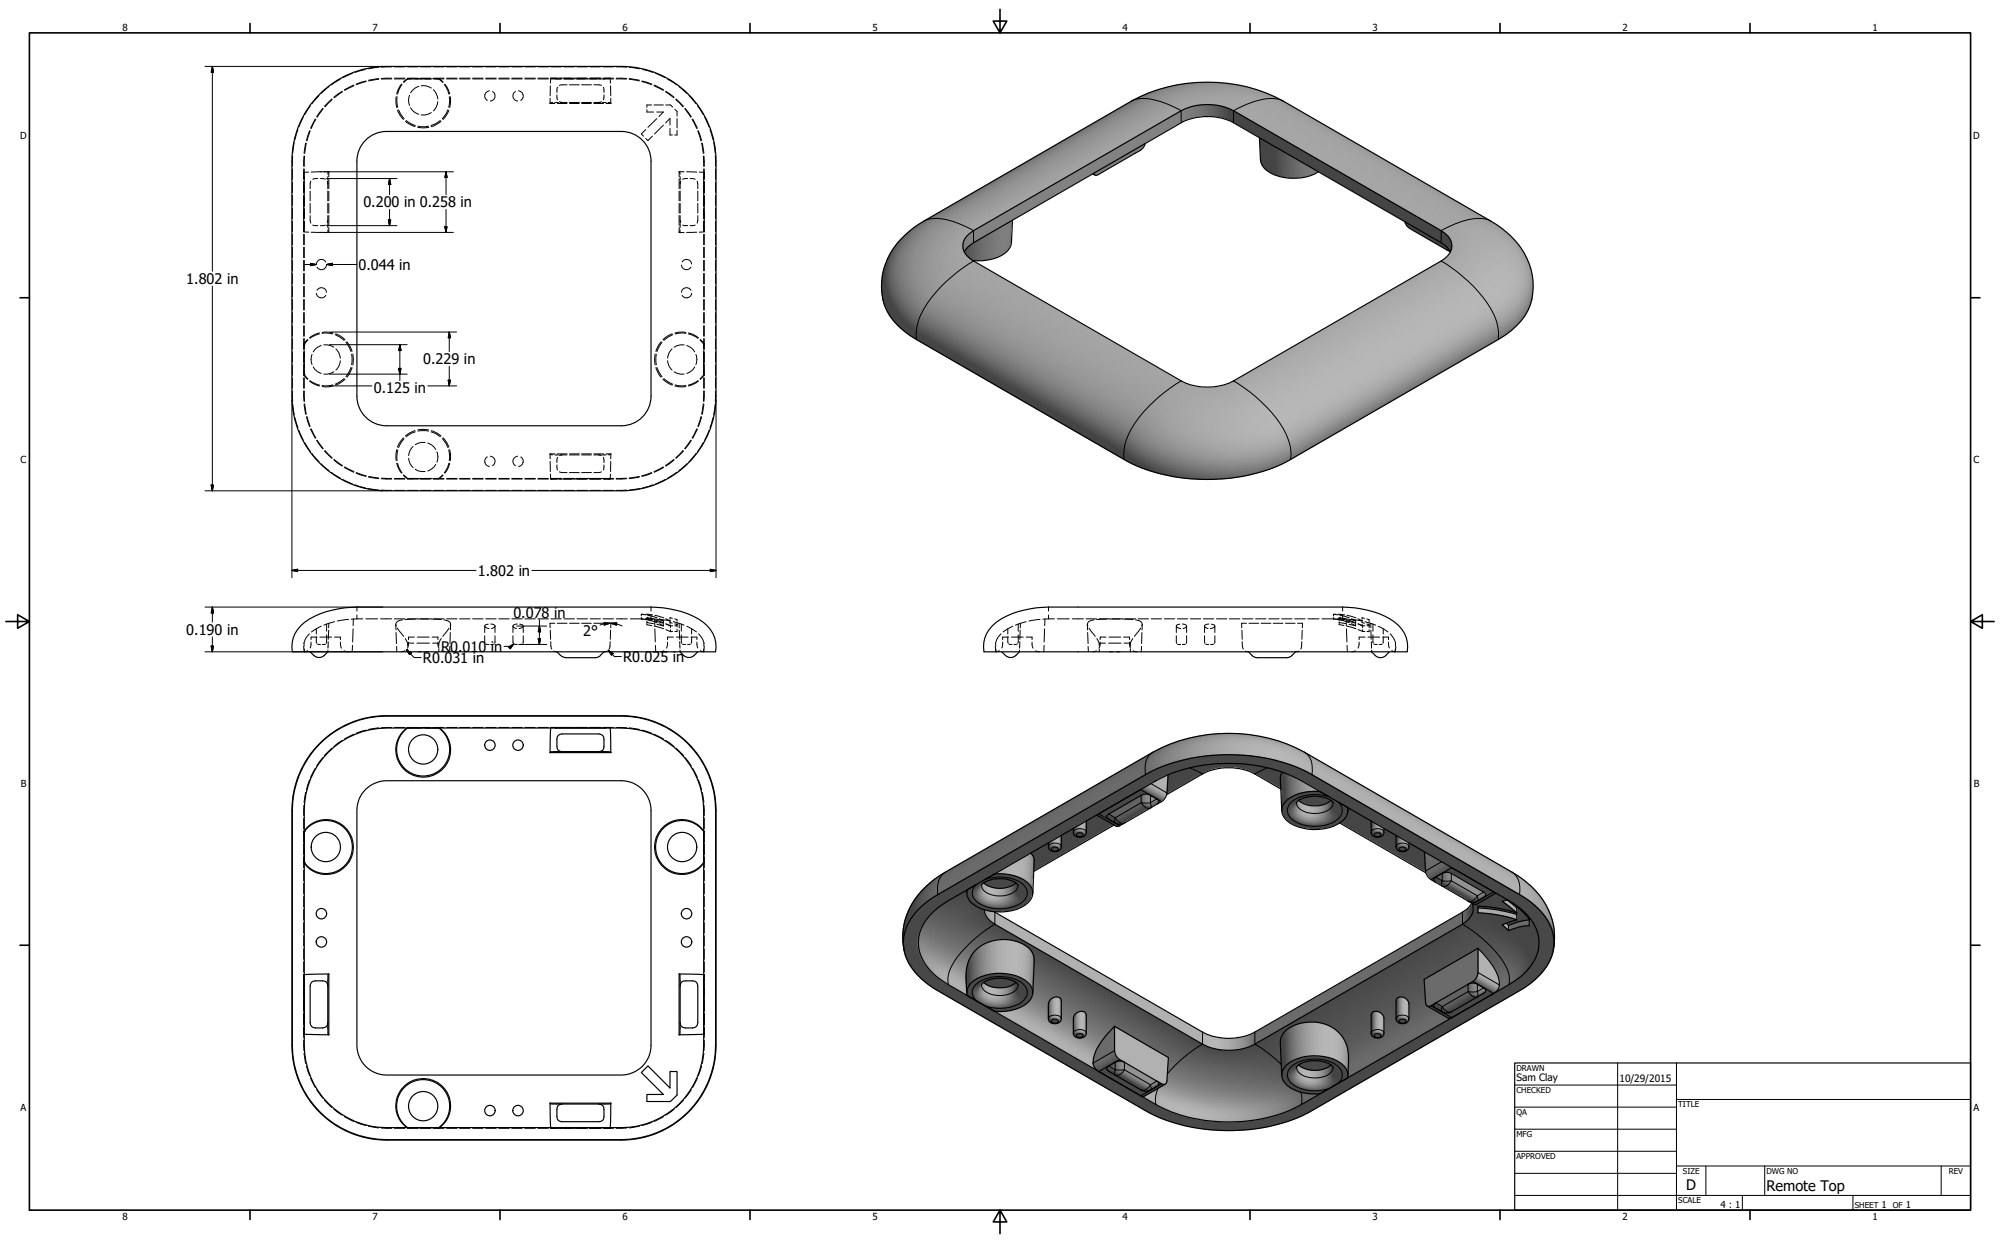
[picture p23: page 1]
SHEET 1 OF 1; DRAWN; CHECKED; MFG; APPROVED; Sam Clay; DWG NO Remote Top; TITLE; SIZE D; SCALE; REV

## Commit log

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2014-12-23 New P-Series Dome by Snaptron in the eagle pcb. Layout done for revision 14.
    [Remote Enclosure v2.3dm]
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2015-01-16 New enclsoure with rev15. Still needs to fix bottom of case supports. Also needs to be split into top and bottom.
2015-01-16 Updating buttons for new, smaller enclosure. Also adding them to blocks. Just need to split the enclosure and snap it back together.
    [Remote r14.3dm]
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2015-02-05 Flipping buttons from active HIGH to active LOW. Required a lot of fiddling.
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2015-02-28 Adding 0.1mm height to enclosure. Redrawing latches to be locked in xyz, not just zy. No longer chopping off bottom of remote.
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2015-06-19 Buttons now have ridges and metal dome switch bumps. They're all done! Now to just get the PCB in, place mounts, and add a lip and snaps.
    [Remote Assembly.0012.iam, Remote Assembly.0014.iam, Remote Assembly.iam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]
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2015-06-26 Fixing rev 19's flaws.
    [Remote Buttons Export.0006.ipt, Remote Buttons Export.ipt, Remote Buttons.0065.ipt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]
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2015-07-01 Fixing revision 20 of buttons. Adding print joiner.
    [Buttons Mold.iam, Buttons Mold_Remote Buttons_1_LY.iam, Buttons Mold_Remote Buttons_1_MP.ipt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]
2015-07-15 Fixing issues on revision 20. Button corner stabilizers, buttons lowered, larger logo and rev text on bottom, less deep logo/text.
    [Bottom Mold.iam, Bottom Mold_RG.ipt, Bottom Mold_Remote Bottom_CR_1.ipt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]
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2015-07-16 Fixing buttons for export rev 21.
    [Remote Buttons Export.0008.ipt, Remote Buttons Export.0009.ipt, Remote Buttons Export.ipt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]
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2015-07-18 CAM for bottom. Needs tabs and a fix for the t-slot milling of the inner tab.
    [Case Bottom.0003.ipt, Case Bottom.0005.ipt, Case Bottom.ipt]
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2015-07-31 Finished CAM for Case Bottom. Now need to replace both tool bits and draw the appropriate trace path for the undercuts.
    [Case Bottom.ipt]
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2015-08-06 Fixing Case Bottom's mating tabs to fit below the border. Re-doing CAM for top of bottom case.
    [Case Bottom.ipt, Case Top.ipt, Remote Top.ipt]
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2015-08-06 Updating assembly with fixed bottom.
    [Case Top.ipt, Remote Assembly.iam, Remote Buttons Export.ipt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]
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2015-08-06 Finishing CAM on case bottom. Now need to replace button pegs.
    [Case Bottom.ipt, Remote Assembly.iam, Remote Buttons Export.ipt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]
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2015-08-07 Redrawing north ridge on case buttons and removing broken north ridge from remote buttons.
    [Case Buttons.ipt, Remote Assembly.iam, Remote Buttons.ipt]
2015-08-07 Fixing remote buttons. Cleaning up.
    [Case Buttons.ipt, Remote Assembly.iam, Remote Buttons.ipt]
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2015-08-13 Fixing CAM files to use separate setups for each tool change.
    [Case Bottom.ipt]
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2015-08-13 Fixed origin point.
    [Case Bottom.ipt]
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2015-08-21 Adding STEP exports. Redrawing PCB entirely to show off battery holder and snaptron buttons. Also realigning it.
    [CR2032 Battery Holder.stp, Case Bottom.stp, Case Buttons.ipt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]
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2015-09-06 Top and bottom case looking good when machined. Could use better alignment/orientatin help when flipping.
    [Case Bottom.ipt, Case Top.ipt]
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2015-09-07 Reducing thickness from 1/8" to 1/10", coupled with the 0.1" clearance means for 0.09" thickness.
    [Case Bottom.ipt, Case Buttons.ipt, Case Top.ipt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]
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2015-09-08 Fixing embossed button peg holder to not have weird edge.
    [Remote Assembly_Remote Bottom_3.stl, Remote Assembly_Remote Buttons_2.stl, Remote Assembly_Remote Top_1.stl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]
2015-09-08 Fixing boss ribs on button.
    [Case Buttons.ipt, Remote Assembly.iam]
2015-09-09 Adding 0.025" of clearance for plastic remote to move around inside wooden case for alignment with buttons on top.
    [Case Bottom.ipt, Case Buttons CAM.ipt, Case Buttons.ipt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]
2015-09-09 Fixing button toolpaths. Also attempting to unify case top and bottom.
    [Case Bottom.ipt, Case Buttons CAM.ipt, Case Top.ipt]
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2015-09-16 Revision 28. Fixing button pegs by making them double wide.
    [Case Buttons.ipt, Eagle PCB rev 21.ipt, Remote Assembly.iam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]
2015-09-16 Fixing revision 28 so that it is printable.
    [Case Buttons.ipt, Eagle PCB rev 21.ipt, Remote Assembly.iam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]
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2015-09-25 Slightly bigger wooden cases to give extra clearance. Also cleaning up how buttons get cut.
    [Case Bottom.ipt, Case Buttons CAM.ipt, Case Buttons.ipt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]
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2015-10-16 Refining outer contour for top and bottom. Needs to fix button height and possibly fit.
    [Case Bottom.ipt, Case Buttons CAM.ipt, Case Buttons.ipt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]
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2015-10-24 Fixing button ridge cutout so tht it always works instead of relying on both the 1/4" flat end mill to match the 1/16" bull nose end mill.
    [Case Bottom.ipt, Case Buttons CAM.ipt, Case Buttons.ipt]
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2015-11-03 Fixing bump on case bottom caused by remote shell not being fully split.
    [Case Bottom.dwg, Case Bottom.ipt, Case Top.dwg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]
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2015-11-10 Widening bottom, narrowing top, each by 0.002" to match each other. Also reducing internal compensation by 0.015", as that much tolerance is unnecessary.
    [Case Bottom.dwg, Case Bottom.ipt, Case Buttons CAM.ipt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]
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2015-11-14 Using conventional strategy to fix button corners.
    [Case Buttons CAM.ipt, Case Top.ipt]
2015-11-18 Slight tweak to case top and bottom's contour. Left in extra C7's to be removed by next commit's fix.py.
    [Case Bottom.ipt, Case Buttons CAM.ipt, Case Top.ipt]
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2015-12-09 Smoothing out top case contour. Fixing parallel/face strategy on buttons.
    [Case Buttons CAM.ipt, Case Top.ipt]
2015-12-09 Shortening buttons from 0.125" (actual 0.120") to 0.105" (actual 0.101").
    [Case Buttons CAM.ipt, Case Buttons.ipt]
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2016-01-15 Fixing slight mistake on case button width. Also making STP files in rev 30.
    [Case Bottom.dwg, Case Buttons CAM.ipt, Case Buttons.dwg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]
2016-01-15 Fixing case button width CAM toolpaths.
    [Remote Assembly.iam]
2016-01-20 Finishing new fixture with four remotes per board. Also added drill registration holes and moves stockpoint to center of Y axis so that the walls on the Y-sides don't need to match any order.
    [Case Bottom.ipt, Case Buttons CAM.ipt, Case Top.ipt]
2016-01-22 Updating drawings to include lower tolerance and corner radius.
    [Case Bottom.dwg, Case Buttons.dwg, Case Top.dwg]
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2016-01-30 Fixing two small issues on case buttons.
    [Case Buttons CAM.ipt]
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2016-02-11 Speeding up last cutout contour. Tightening up top case flat cut.
    [Case Bottom.ipt, Case Top.ipt]
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2016-02-12 Adding missing bluetooth radio cut out.
    [Remote Bottom Print Assembly.iam, Remote Bottom.ipt]
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2016-04-08 Adding new fixtures for vacuum machining. Just need to figure out relative position of tops and bottoms (now that heights have been taken care of).
    [Case Bottom.ipt, Case Top.ipt, Fixture Assembly.iam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]
2016-04-09 New Fixture CAM. Got the entire flat end mill toolpath finished. Just need ball end mill.
    [Case Bottom.ipt, Case Top.ipt, Fixture Assembly.iam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]
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2016-04-09 Finishing up new fixture. Contour side ball end mill done. Ready to print.
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2016-04-13 WCS at sleected point on fixture.
    [Fixture Assembly.iam, Fixture Base.ipt]
2016-04-14 Adjusting fixture measurements and toolpaths. Also adding drill holes.
    [Fixture Assembly.iam, Fixture Base.ipt]
2016-04-21 Updating fixtures.
    [Case Bottom.ipt, Case Top.ipt, Fixture Assembly.iam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]
2016-05-23 Updating CAM for new 9" fixture. Still need vacuum holes drilled.
    [Case Bottom.ipt, Case Top.ipt, Fixture Assembly.iam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]
2016-05-23 Adding new vacuum fixture drill holes. Ready to machine vacuum fixture!
    [Fixture Assembly.iam]
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2016-05-27 Switching fixture base flat from 1/4" to 1/2" flat end mill. Also adding playwood cutout.
    [Fixture Plywood Cut-out.dwg]
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2016-06-15 Adjusting fixture drills.
    [Fixture Assembly.iam, Fixture Base.ipt, Fixture Plywood Cut-out.dwg]
2016-06-20 Updating fixture to use new models for smaller fixture case thinning.
    [Case Bottom Fixture.ipt, Case Bottom.ipt, Case Top Fixture.ipt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]
2016-06-21 Adjusting sizes on new case fixture negatives.
    [Case Bottom Fixture.ipt, Case Top Fixture.ipt, Fixture Assembly.iam]
2016-06-22 Finishign up cases on fixture. Time to shine!
    [Case Bottom Fixture.ipt, Case Bottom.ipt, Fixture Assembly.iam]
2016-06-23 Pushing contour half of case back a bit to allow for room to machine all the way around. Optimized fixture contour making.
    [Fixture Assembly.iam]
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2016-06-23 Adding handle to fixture.
    [Fixture Assembly.iam, Fixture Base.ipt]
2016-06-24 Adjusting contour fixture size to make room. Maybe a bit too spacious?
    [Case Bottom Fixture.ipt, Case Top Fixture.ipt, Fixture Assembly.iam]
2016-06-24 Adjusting fixture sizes to fit more snugly. Also increasing top case drill holes for more vacuum suction.
    [Case Bottom Fixture.ipt, Case Top Fixture.ipt, Case Top.ipt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]
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2016-07-07 Adding superellipse and button fixture base.
    [Button Fixture Base.ipt, Lame Curve.dwg]
2016-07-07 Button fixture assembly (pre-cam)
    [Button Fixture Assembly.iam, Button Fixture Base.ipt, Case Buttons CAM.ipt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]
2016-07-08 New button fixture and button toolpaths on vacuum fixture. Ready to cut!
    [Button Fixture Assembly.iam, Button Fixture Base.ipt, Case Buttons CAM.ipt]
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2016-07-11 Fixing pre-drill for top contour.
    [Fixture Plywood Cut-out.dwg]
2016-07-13 Thickening negatives for tighter contour fit. Moving from 0.015" to 0.010". Might need to compromise on 0.0125"
    [Case Bottom Fixture.ipt, Case Top Fixture.ipt, Fixture Assembly.iam]
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2016-07-13 Adding cleaning toolpath for fixture. Useful for tightening as well. Can possibly merge in 5002.
    [Case Top Fixture.ipt, Fixture Assembly.iam]
2016-07-15 Updating button fixture. Ready to cut!
    [Button Fixture Assembly.iam, Fixture Assembly.iam]
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2016-07-19 Revision 3 of button vacuum fixture. This time using slots on the bottom of each button, used to hold the button in place during top milling.
    [Button Fixture Assembly.iam, Button Fixture Base.ipt, Button Fixture CAM.ipt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]
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2016-07-21 Longer button fixture to handle vacuum mistake. Tightening up with new hold downs.
    [Button Fixture Assembly.iam, Button Fixture Base.ipt, Button Fixture CAM.ipt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]
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2016-09-14 New button fixture.
    [Button Fixture Assembly.iam, Button Fixture CAM.ipt, Case Buttons CAM.ipt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]
2016-09-14 Plywood cut out for button fixture.
    [Fixture Plywood Cut-out.dwg]
2016-09-27 Widenin to 8", correcting drill lengths.
    [Button Fixture Assembly.iam, Button Fixture Base.ipt, Button Fixture CAM.ipt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]
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2016-10-06 Adding peg holes to remote and case. Case fixture still needs drills and holes.
    [Button Fixture Assembly.iam, Button Fixture CAM.ipt, Case Bottom Fixture.ipt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]
2016-10-12 Under case button booster. Let's hope it's not too big or too small.
    [Under Case Button Booster.ipt, Under Case Button Booster.stl, Under Case Button Booster.stp]
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2016-10-12 Fixing corner rolls on buttons.
    [Button Fixture CAM.ipt]
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2016-10-14 New case fixture. Rearranged to fit everything in, including new vacuum holes. Also adding pegs into fixture and cases.
    [Case Bottom Fixture.ipt, Case Bottom.ipt, Case Top Fixture.ipt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]
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2016-10-14 Updating fixture plywood cutout for new 20'x30' boards.
    [Fixture Base.ipt, Fixture Plywood Cut-out.dwg]
2016-10-19 Correcting pegs.
    [Case Bottom Fixture.ipt, Case Bottom.ipt, Fixture Assembly.iam]
2016-10-31 Increasing fixture thickening from 0.010" to 0.020". Looser fit on vacuum fixture, but pegs should take care of that.
    [Case Bottom Fixture.ipt, Case Top Fixture.ipt, Fixture Assembly.iam]
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2016-12-09 Rev. 32 of remote enclosure. Cut out magnets, scooped out bottom remote, widen top remote opening, narrowed buttons to better handle tolerance on wooden case.
    [Case Buttons.ipt, Remote Assembly.iam, Remote Bottom Print Assembly.iam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]
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2017-01-26 Under Case Photo Holder is now 0.75" wide and a little shorter so it doesn't interfere with the button paddle. Used for taking 360° photos of a remote. Also can be used to stand remote sup for displa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
    [Under Case Photo Holder.ipt, Under Case Photo Holder.stl]
2017-01-26 New fixture for glueing remotes. Holds remotes in place during glue curing process. Holds 12 remotes in a 12" x 12" x 0.75" high plywood board.
    [Fixture Glue.ipt]
2017-01-28 Nearly finished with rev 33. Includes united button array with overhang that grips onto the remote top. Also redrawn button paddles and flattened remote top and bottom. Still need to fix print connec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
    [Case Buttons.ipt, Remote Assembly.iam, Remote Bottom Print Assembly.iam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]
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2017-01-28 Adjusting Case to have straight interior edges. Still need to finish the fixture.
    [Case Bottom Fixture.ipt, Case Bottom.ipt, Case Buttons.ipt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]
2017-01-31 Finishing revision 33 of wood enclosure and fixture. Split case fixture into a Pocket Fixture and a Contour Fixture w/ Vacuum.
    [Case Bottom Fixture.ipt, Case Bottom.ipt, Case Top Fixture.ipt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]
2017-01-31 Cleaning up archive. Also updating fixture plywood cutouts.
    [Fixture Base.ipt, Fixture Plywood Cut-out.dwg, Remote Assembly.iam]
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2017-03-16 Adding offsets to bottom height of contour fixture. Also deepening pegs in both fixture and in case.
    [Case Bottom Fixture.ipt, Case Bottom.ipt, Case Top Fixture.ipt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]
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2017-03-29 Adjusting fixture offsets to be 0.015" instead of 0.010". Less of a hold but now the pocketed out blank fits on the contour.
    [Case Bottom Fixture.ipt, Case Top Fixture.ipt, Fixture Assembly.iam]
2017-03-31 Updating pocket fixture.
    [Fixture Assembly.iam, Fixture Base.ipt]
2017-03-31 Just a tiny bit small fixture contours.
    [Case Bottom Fixture.ipt, Case Top Fixture.ipt, Fixture Assembly.iam]
2017-04-05 Expanding out to a 15X fixture. Moving top drill holes closer in. Adding in all four ejection pockets.
2017-04-05 Deepening pin and adjusting depth for contour cut. Still need to inset the fixture offset.
2017-04-06 Moving fixture offset to 0.015" from a huge 0.020".
    [Case Bottom Fixture.ipt, Case Top Fixture.ipt]
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2017-04-11 Rev 38: realigned peg holes for buttons, updated button fixture. Pegs now mate the wood buttons and the plastic remote buttons.
    [Button Fixture Assembly.iam, Case Buttons CAM.ipt, Case Buttons.ipt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]
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2017-04-21 Bigger drill holes for case top. Fixing alignment issues on contour fixture (ugh). Reducing case fixture offset to 0.015".
    [Case Bottom Fixture.ipt, Case Top Fixture.ipt, Case Top.ipt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]
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2017-04-28 Addng toolpaths to lower the z plane a bit to smooth ovr differences on plywood fixture.
    [Button Fixture Assembly.iam, Button Fixture Base.ipt, Button Fixture CAM.ipt]
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2017-05-02 Now accounting for the reality of wood warping during machining. 0.01" on 2 of 4 buttons! And 0.02" machining endgrain and 0.01" maching along the grain. Call it the fudge factor. It's neatly contain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
    [Button Fixture Assembly.iam, Button Fixture CAM.ipt, Case Buttons CAM.ipt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]
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2017-05-11 New button fixture to handle wider buttons that take machine warp into account.
    [Button Fixture Assembly.iam, Button Fixture Base.ipt, Button Fixture CAM.ipt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]
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2017-05-18 New button fixture wtih split button groups. Also better at handling button size changes to fit case.
    [Button Fixture Assembly.iam, Button Fixture CAM.ipt, Case Buttons CAM.ipt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]
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2017-05-23 Fixing repositioning issue in post processor. Also adjusting sizes of buttons.
    [Button Fixture Assembly.iam, Button Fixture Base.ipt, Button Fixture CAM.ipt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]
2017-05-24 Beginning new fixture with new clamps.
    [Fixture Assembly.iam, Fixture Base.ipt]
2017-05-26 Redesigned case fixtures to be split. Needs CAM.
    [Case Bottom Fixture.ipt, Case Top Fixture.ipt, Fixture Assembly.iam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]
2017-05-26 CAM fixture done. Upgraded to Inventor HSM 2018 for duplication pattern.
    [Button Fixture Base.ipt]
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2017-05-27 Fixing broken fixture leveling. ALso adjusting height of dowel pins. Shouldn't there be some more room?
    [Button Fixture Assembly.iam, Button Fixture Base.ipt, Button Fixture CAM.ipt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]
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2017-06-02 Revised CAM 15X fixture. Needs to account for ~0.030" difference in height between plastic insert and wood case.
    [Case Bottom Fixture.ipt, Case Bottom.ipt, Case Top Fixture.ipt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]
2017-06-02 Adjusting size to 0.005" for case fixture offsets to better find the true values.
    [Case Bottom Fixture.ipt, Case Buttons.ipt, Case Top Fixture.ipt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]
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2017-06-07 Adjusting direct edits for pocket fixture.
    [Case Top Fixture.ipt, Case Top.ipt, Fixture Assembly.iam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]
2017-06-09 New models for pocket fixture to deal with machine discrepancies.
    [Case Bottom Contour Fixture.ipt, Case Bottom Pocket Fixture.ipt, Case Top Contour Fixture.ipt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]
2017-06-09 Can't believe I had to do this but this is now verified latest toolpaths with responsive updates to single axis oh man i'm too tired to figure out what i'm writing here, just read the previous couple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
    [Case Bottom Contour Fixture.ipt, Case Bottom Fixture.ipt, Case Bottom Pocket Fixture.ipt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]
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2017-06-14 Sizing contour fixture.
    [Case Top Contour Fixture.ipt]
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2017-06-21 Readjusting pocket and contour fixture offsets to guarantee fit.
    [Case Bottom Contour Fixture.ipt, Case Top Contour Fixture.ipt, Fixture Assembly.iam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]
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2017-06-22 Pocket fixture done.
    [Case Bottom Pocket Fixture.ipt, Case Top Pocket Fixture.ipt, Fixture Assembly.iam]
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2017-07-06 Updating cutout for new 60" fixtures.
    [Fixture Plywood Cut-out.dwg]
2017-07-10 Extending fixture to 30X.
    [Fixture Assembly.iam, Fixture Base.ipt]
2017-07-10 Finished with 30X fixtures. Now time to make new CAM toolpaths.
    [Fixture Assembly.iam, Fixture Base.ipt]
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2017-07-12 Pedesl Fixture. Needs toolpaths.
    [Pedestal Fixture Assembly.iam, Pedestal Fixture Base.ipt, Pedestal Fixture CAM.ipt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]
2017-07-12 Fixture toolpaths done, now need pedestal toolpaths.
    [Pedestal Fixture Assembly.iam, Pedestal Fixture Base.ipt, Pedestal Fixture CAM.ipt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]
2017-07-12 Finishing pedestal fixture toolpaths. Ready to cut!
    [Pedestal Fixture Assembly.iam, Pedestal Fixture CAM.ipt, Pedestal.ipt]
2017-07-12 Fixing collisions and smoothing out spiral on contours. Now actually ready to cut!
    [Pedestal Fixture CAM.ipt]
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2017-07-17 Narrower fixture for pedestal. Only 16" x 8".
    [Pedestal Fixture Assembly.iam, Pedestal Fixture Base.ipt, Pedestal Fixture CAM.ipt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]
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2017-07-19 Shortening pedestal to fit a 13/16" board.
    [Pedestal Fixture Assembly.iam, Pedestal Fixture CAM.ipt, Pedestal.ipt]
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2017-07-20 Adjustable 30X and 15X fixture.
    [Case Bottom Contour Fixture.ipt, Case Bottom Pedestal Fixture.ipt, Case Bottom Pocket Fixture.ipt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]
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2017-07-27 Pedestal measurements. Adding extra holes. Need to mount on the fixture.
    [Glue Curing Holder.ipt, Pedestal Fixture Assembly.iam, Pedestal Fixture CAM.ipt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]
2017-07-27 Offsetting pedestal contour to allow for replaceable mount.
    [Pedestal Fixture Assembly.iam, Pedestal Fixture CAM.ipt]
2017-07-27 Widening insets on fixture to better handle differences between CNC machines.
    [Case Bottom Contour Fixture.ipt, Case Top Contour Fixture.ipt, Fixture Assembly.iam]
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2017-07-28 Moving remotes around on both fixtures to get better clearance. Can only do this when both fixtures are being built.
    [Fixture Assembly.iam, Fixture Base.ipt]
2017-07-29 Revert "Moving remotes around on both fixtures to get better clearance. Can only do this when both fixtures are being built."
    This reverts commit ecf329b368d75e1306c39e7efffbcdbb3b57a68f.
    [Fixture Assembly.iam, Fixture Base.ipt]
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2017-08-01 Updating pedestal to better clear the contour fixture.
    [Pedestal Fixture CAM.ipt]
2017-08-02 Final pocket fixture measurements. Need to measure contour fixture.
    [Case Bottom Pocket Fixture.ipt, Case Top Pocket Fixture.ipt, Case Top.ipt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]
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2017-08-03 Redrawing Button Fixture for 2 fixtures. Guesstimating a 24" board will fit (32 button sets = 4 button sets per 3").
    [Button Fixture Base.ipt]
2017-08-03 Finishing button fixture. Now just need to update CAM.
    [Button Fixture Assembly.iam, Button Fixture Base.ipt, Case Buttons CAM.ipt]
2017-08-04 Finish CAM for new button fixtures. Time to build.
    [Button Fixture Assembly.iam]
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2017-08-04 Nudging up pedestal to handle clearance when flipping.
    [Pedestal Fixture Assembly.iam, Pedestal Fixture CAM.ipt]
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2017-08-08 Updating button fixtures to use 3x5 instead of 2x8.
    [Button Fixture Assembly.iam]
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2017-08-09 Narrowing pocket fixture to account for differences between woods.
    [Case Bottom Pocket Fixture.ipt, Case Top Pocket Fixture.ipt, Fixture Assembly.iam]
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2017-08-30 Ensuring buttons are machined correctly. Also updating plywood cutout for 5" and 6" button fixtures.
    [Button Fixture Assembly.iam, Case Buttons CAM.ipt, Fixture Plywood Cut-out.dwg]
2017-08-30 Adding 0.015" to height of button paddle to fix depressiong between buttons.
    [Remote Buttons Print Assembly.iam, Remote Buttons Print Assembly.stl, Remote Buttons.ipt]
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2017-08-31 Tightening pedestal cam.
    [Pedestal Fixture Assembly.iam, Pedestal Fixture CAM.ipt, Pedestal.ipt]
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2017-09-06 Adjusting pocket fixture numbers.
    [Case Top Contour Fixture.ipt, Fixture Assembly.iam]
2017-09-08 Calibrating pocket and contour fixture.
    [Case Bottom Pocket Fixture.ipt, Case Top Contour Fixture.ipt, Case Top Pocket Fixture.ipt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]
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2017-09-14 Adjusting button fixture and buttons.
    [Button Fixture Assembly.iam, Case Buttons CAM.ipt]
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2017-09-16 Potential revert alert: Raising remote button by 0.010" and adding 0.002" to the top of the paddle and to the bottom of the paddle.
    [Remote Buttons Print Assembly.iam, Remote Buttons Print Assembly.stl, Remote Buttons.ipt]
2017-09-21 Moving pocket fixture out to 0.150" from edge to better handle variation in wood. Also adding contour alignment holes.
    [Fixture Assembly.iam]
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2017-09-22 Pocket fixture to 60".
    [Fixture Assembly.iam, Fixture Base.ipt]
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2017-10-04 Updating fixture for 30X.
    [Case Top Contour Fixture.ipt, Case Top Pocket Fixture.ipt, Case Top.ipt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]
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2017-10-06 Widening pocket fixture to accomodate toolpaths that strike the hold down clamps. Also calibration for pocket fixture complete.
    [Case Bottom Pocket Fixture.ipt, Case Top Pocket Fixture.ipt, Fixture Assembly.iam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]
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2017-10-26 10X Pedestal Fixtures. Ready to cut!
    [Pedestal Fixture Assembly.iam, Pedestal Fixture Base.ipt]
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2017-11-07 Calibration and adding partial button fixture toolpaths.
    [Button Fixture Assembly.iam]
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2017-11-16 Button high toolpaths that are 0.005" shorter buttons.
    [Button Fixture Assembly.iam, Case Buttons CAM.ipt, Case Buttons.ipt]
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2017-12-02 Shortening buttons. 4 passes on buttons downcut.
    [Button Fixture Assembly.iam, Case Buttons CAM.ipt, Case Buttons.ipt]
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2017-12-06 New magnet insertion jigs. Won't resolve on sculpteo for some reason.
    [Magnet Bottom Insertion Jig.ipt, Magnet Bottom Insertion Jig.stl, Magnet Top Insertion Jig.ipt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]
2017-12-07 Fixing magnet insertion jig. Not sure what changed but it works now.
    [Magnet Top Insertion Jig.ipt, Magnet Top Insertion Jig.stl]
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2018-01-30 64X case fixtures that now fit in a 8' x 4' plywood board.
    [Case Bottom Contour Fixture.ipt, Case Top Contour Fixture.ipt, Fixture Assembly.iam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]
2018-01-30 60X button fixture.
    [Button Fixture Assembly.iam, Button Fixture Base.ipt]
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2018-03-17 Adjusting pedestal fixture to 57". Also adjusting CAM insets for fixture.
    [Case Bottom Contour Fixture.ipt, Case Bottom Pocket Fixture.ipt, Case Top Contour Fixture.ipt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]
2018-03-28 Adding new Pedestal T track and Pedestal hold-down on pocket fixture.
    [Fixture Assembly.iam, Fixture Base.ipt]
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2018-03-30 Adjusting pedestal cuts. 10X fixture now works.
    [Fixture Assembly.iam, Fixture Base.ipt]
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2018-04-24 Moving standoffs on conotur fixture over to the center of the fixture.
    [Fixture Assembly.iam]
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2018-05-03 Adjusting button sizes, moving button fixture up an inch to match new triple pocket fixture.
    [Button Fixture Assembly.iam, Button Fixture Base.ipt, Case Buttons CAM.ipt]
2018-05-09 Lengthening button fixture to 7 sets. Adding button pocket fixture hold downs.
    [Button Fixture Assembly.iam]
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2018-05-15 Calibrating N/S case top on conture fixture.
    [Case Top Contour Fixture.ipt, Fixture Assembly.iam]
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
